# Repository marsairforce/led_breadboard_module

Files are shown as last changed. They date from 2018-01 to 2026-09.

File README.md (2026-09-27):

# A LED indicator module for breadboard development

I became frustrated at having to repeat the boring work of foraging parts, assembling, and then testing status LED circuits for breadboard development with digital logic circuits.

## The Problem

- Most microcontroller projects on a breadboard benefit from several LEDs to show status.
- LEDs operate at voltages lower than logic levels, so require current limiting resistors.
- LEDs typically draw about 10mA or more per LED. Sometimes it is not desirable to load the digital I/O pins from the microcontroller.
  - Quite often a single package device is not capable of sourcing the total current required for a lot of LEDs. For example a 74HC595 is typically capabale of sourcing or sinking up to 70mA. If all of their outputs are active the sum of their currents must not exceed this.
- If we use a simple current limiting resistor, we need to compute the value depending on the forward voltage of the LED and the desired voltage we are working with (today this is either 5V or 3.3V)

So in practice we would would want to set up some kind of buffer with current limiting resistors for the LEDs:

- some transistors and resistors
- or a driver IC like the ULN2803

The whole effort of building LEDs, driver circuits on a breadboard every time is error prone.

And it inconveniently takes up a lot of space on your breadboard.

So I set out to build a module that could be reused between projects.

- [Version 3](./doc/v3.md)
- [Version 2](./doc/v2.md)
- [Version 1](./doc/v1.md)

This project started of as what seemed like a simple activity but turned into a mechanism for a lot of learning.

See Also: [Transistor Theory](./doc/transistor_theory.md)

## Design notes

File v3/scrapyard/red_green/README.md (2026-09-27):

# A red-green LED module for breadboard

This makes use of a bi-color LED. This is a two terminal device. If you supply power one direction it shines red. But if you revese the polarity it shines green.

I wanted to create an easy to use module that lets you change the color and have a mode where there was no output at all (off)

Because each diode has its own different forward voltage the challenge is to use a different resistor or limiting the current. Otherwise the green LED would appear dimmer or the red would appear brighter.  If I just use the constant current sink (or source) this should solve the current problem.

And then a H bridge approach to power the led in alternate directions. Like a DC motor.
But then this requires several small transistors. A first design reduced the package count by using packages with two devices in them.
This had a nice side effect of learning about the SOT-363 package. But I was able to furrher simplify this using a single H bridge IC.
Yes. it is rediculous and over engineered. But it is functional, not very expensive with available parts, and not very much board space. I can see myself adding this indicator to arbitrary projects now.

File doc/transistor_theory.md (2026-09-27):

# Transistor Theory

Before we can talk about transistors it is worth noting

Transistors are inheritly analog devices. They have a 'linear' region and a 'saturation' region.

In the linear region the device is not fully open, where as saturation means we have provided enough inptut to fuly turn on the device.

## Bipolar Transistors

Bipolar Junction Transistors (BJT)s uses two types of charge carriers to conduct electricity: free electrons and electron holes. The junctionrefers to the p-n semiconductor junctions inside the device where different types of silicon meet. A BJT has two of these junctions.

There are two main kinds of BJTs

- NPN: Made of a p-type base sandwiched between two n-type regions (Collector and Emitter). Electrons flow from emitter to collector when a positive current enters the base. They are the most common type because electrons move faster than holes.
- PNP: Made of an n-type base sandwiched between two p-type regions. Current flows in the opposite direction, utilizing electron holes.

BJTs are current-controlled devices. You must pay attention to how much current flows into the base to control the larger current flowing through the collector.

The transistor has a 'gain', $h_{FE}$. This is the static (DC) forward current gain in a common-emitter configuration. Is is the ratio of collector current $I_{C}$ to base current $I_{B}$.

Within the linear region BJTs are used as analog amplifiers. Used extensively in audio amplifiers, radio frequency (RF) circuits, and sensors where signals need a linear boost.

Within the saturation region BJTs are used for discrete Switching, used to turn on indicator lights, buzzers, or relays in simple electronic circuits or for digital logic.

**Common emitter** means:

- For a NPN transistor we measure the current going into the base and into the collector.
- For a PNP transistor we measure the current coming out of the collector and out of the base.

### Some Bipolar Transistor Devices

For the LED modules I investigated packages that contain 1 and 2 transistor devices.

| Transistor 1 | Transistor 2 | Part Number | Package | Vceo | Ic | $h_FE$ | Vce(sat) | Vbe(on) |
|-|-|-|-|-|-|-|-|-|
| NPN | (none) | MMBT3904 | SOT23-3 |  40 V | 200 mA | 100-300 (at 10mA) | 0.2V (at 10mA)<br> 0.3V (at 50mA) | 0.65V-0.85V |
| NPN | NPN | MMDT3904 | SOT-363 |  40 V | 200 mA | 100-300 (at 10mA) | 0.2V (at 10mA)<br> 0.3V (at 50mA) | 0.65V-0.85V |
| PNP | (none) | MMBT3906 | SOT23-3 | -40 V | -200 mA | 100-300 (at -10mA) | -0.3V (at 50mA) | -0.65V - -0.85V |
| PNP | PNP | DMMT3906 | SOT-363 | -40 V | -200 mA | 100-300 (at -10mA) | -0.3V (at 50mA) | -0.65V - -0.85V |
| NPN | PNP | BC846 | SOT-363 |  65V | 100mA | 110-800 (by suffix group) | 0.25 (at 10mA) <br> 0.6V (at 100mA) | 0.58V - 0.77V |

- Vceo (Collector-Emitter Voltage): The absolute maximum voltage the transistor can withstand between the collector and emitter when the base is open. Your circuit voltage should ideally be 20–50% below this rating for safety.
- Ic (Continuous Collector Current): The maximum continuous current the transistor can handle. For standard switching, ensure your load demands significantly less than this limit.
- hFE or β (DC Current Gain): The ratio of collector current to base current (Ic / Ib). Crucial Note: This value drops drastically when the transistor is fully saturated (turned hard ON as a switch). Always look at the datasheet curves, not just the maximum value.
- Vce(sat) (Collector-Emitter Saturation Voltage): The voltage drop across the transistor when it is fully turned ON. Multiplying this by your Ic gives you the conduction power loss (P = Vce(sat) x Ic), which tells you how hot it will get.
-Vbe(on) (Base-Emitter On Voltage): The voltage required across the base and emitter to start turning the transistor on (typically around 0.6V to 0.7V for silicon).
- *MOSFET Transistors*

## Metal Oxide Semiconductor Field Effect Transistor

A MOSFET has three terminals:

- Source (S): Where the charge carriers (electrons or holes) enter the channel.
- Drain (D): Where the charge carriers leave the channel.
- Gate (G): The control terminal that acts like a tap or valve.

MOSFET (Metal Oxide Semiconductor Field Effect Transistor)s are voltage-controlled devices. When you apply a voltage to the Gate, it creates an electric field through the oxide layer. This electric field either opens or closes a conductive channel between the Source and the Drain, allowing a large amount of current to flow with almost no current drawn by the gate itself.

Like BJTs, there are two main kinds of MOSFETS

- N-Channel (NMOS): Turns on when the gate voltage is positive relative to the source. Electrons flow from source to drain. They are generally faster and more efficient.

- P-Channel (PMOS): Turns on when the gate voltage is negative relative to the source. Current flows in the opposite direction using electron holes.

MOSFETs are almost exclusively used in their saturation mode, in this mode they make nearly perfect switches.

MOSFETs require almost zero continuous current at the gate, making them highly efficient for high-speed switching and power applications.\(V_{DSS}\).

They do have

- A gate capacitance. Storing a small bit of charge, the gate works like a capacitor. A higher gate capacitance requires more energy to change the state fo the MOSFET.
- A very small "on" resistance.

### Some popular MOSFET Devices

For the LED modules I investigated packages that contain 1 and 2 transistor devices.

| Transistor 1 | Transistor 2 | Part Number | Package | Vdss | $I_{d}$ | Vgs(th) | Rds(on) | Qg |
|-|-|-|-|-|-|-|-|-|
| NMOS | (none) | BSS123LT1G | SOT23-3 | 100 V | 170 mA | 2.6 V | 6.0 Ω (at Vgs = 10V) | 0.68 nC |
| NMOS | NMOS | 2N7002DW | SOT-363 | 60 V | 115 mA | 2.0 V| 7.5 Ω (at Vgs = 5V) | 0.35 nC |
| PMOS | (none) | BSS84LT1G | SOT23-3 | -50 V | -130 mA | -2.0 V | 10.0 Ω (at Vgs = -5V) | 0.60 nC |
| PMOS | PMOS | BSS84AKS | SOT-363 | -50 V | -160 mA | -2.1 V | 7.5 Ω (at Vgs = -5V) | 0.35 nC |
| NMOS | PMOS | NTJD4105CT1G | SOT363 | N: 20 V <br> P: -8 V |  P: -8 VN: 630 mA <br> P: -775 mA | N: 1.5 V  <br> P: -1.5 V | N: 0.375 Ω (at 4.5V) <br> P: 0.260 Ω (at -4.5V) | N: 0.62 nC <br> P: 0.82 nC |

- Vdss (Drain-Source Voltage): The maximum voltage the MOSFET can block between the drain and source when turned off.
- Id (Continuous Drain Current): The maximum current the device can handle. Note that this is heavily dependent on temperature and proper heat sinking.
- Vgs(th) (Gate-Source Threshold Voltage): The voltage at which the MOSFET just barely begins to conduct. Warning: Do not use this as your driving voltage. A threshold of 2V means it is barely passing microamps.
- Rds(on) (Static Drain-Source On-Resistance): The internal resistance when the MOSFET is fully turned ON. This determines your power loss (P = $I_{d}^2$ * Rds(on)). Lower resistance means less heat. Crucial: Always check what Vgs voltage was used to achieve that Rds(on) rating. If the datasheet specifies Rds(on) at VgsGS = 10V, it will run incredibly hot or fail if you try to drive it with a 3.3V microcontroller.
- Qg (Total Gate Charge): The amount of electrical charge needed to fully turn the gate on and off. Because the gate acts like a capacitor, a high Qg requires a strong gate-driver circuit to switch quickly without overheating.

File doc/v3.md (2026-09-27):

# LED Breadboard Module Version 3

Taking what I have learned from the v2.1 design:

- There is no point in having a pulldown resistor on the base of the transistor. These are bipolar and do not need this pulldown like a MOSFET would.
- The LED and transistors get kind of hot when pushing more than 5v into them. This is beacuse the current is proportional to voltage and I just had a simple current limiting resitor for the LED.
- The current through the LED was kind of high, about 20 mA each. We can use much less, under about 10 mA and get the same useful brightness.
- The base resistor is too small. For the amount of gain in the transitor, we are sinking more current into the transistor.
  This causes a lower impedance and could load digital logic or IO ports more than what I had designed these self-buffering LED indicators to do for us.

## Design Constraints

I have learned to state what it is I want to achieve up front so this is my road map.

My priority at this time

- Support a range of input voltages (so a constant current source for the LED)
- High impedance control inputs (to not load the signal we are monitoring)
- Option for an active low input to control the LED.
- Use an 0806 package for LED, larger, easier to see?
  - no. more investigation shows larger packages do not make a brighter LED.
- A mode to allow a bi-color LED to be operated with a control signal and an output enable.
  - This turned out to be pointless.
  At the time I had this point I was thinking there would be a device with true anti-parallel wiring, two LEDs with two wires on the package.
  In practice the LEDs I have found with more than one color just have multiple input pins.
- Support for standard logic IC families - to create a breadboard module for a 74HC595 (a serial in, parallel out shift register), that functions as the 74HC595 should, but with lights for the outputs. And in general other popular ICs, like discrete logic gates.
  I was imagining a TSSOP package IC with the drivers so the footprint is a slightly larger DIP kind of package with the same pin out of the device.
- Investigate a modyke where A single LED can be dropped into breadboard.
  A three terminal device that has two pins to go into the breadboard power rails and a pin that can go into the row that presumably has an IC pin.
  So we can just drop an indicator for a single pin of an existing IC
- A 'universal LED'. A Two terminal device that looks like a 3mm or 5mm thru hole LED. It accepts power, any polarity and a range of voltage. It just lights up. Simple indicator, like a regular old light bulb, but its a LED.

## Learning and Theory

I did a side quest to investigate and learn about different topologies:

- high side drive
- low side drive
- constant current source
- constant current sink

The notes are in the [building blocks](building_blocks.md) document.

While iterating with these designs I discovered there are devices that have two transistors in a single package. The use case being for multiple LED on a module we could benefit from using a dual device in a single package. My notes and discovery are in the [transistor theory](transistor_theory.md) document.

Another discovery during this round of design was realizing how much smaller a SOT-363 package is from a SOT23-3. It was enough that it made more sense to just make every device be in the SOT-363 package and not even use SOT23-3 packages.

The next discovery was there exists a product that provides constant current regulation in a single package. I no longer need to build out my own discrete components. Four parts become one part.

And then the realization, I still need pull down resistors for the MOSFET transistors, But instead of individual resistors I can use a resistor network. Single package in a 1206 footprint with 8 100K resistors.

## Variants

Since some of the constraints and use cases are contradictory, I decided I would just define a model (uncreatively using letters) to articulate each variant.

Weather or not we actually get around to designing and building these has yet to be seen.

| Model | # LEDs | Color | Drive | Active High | Active Low |  OE | Desc |
| ----- | --- | ----- | ----- | :---: | :---: | :---: | ---: |
| A | 8 | Red | High  | * | | | 8 red LED, high side drive, active high control |

So model "A" is the only one I have had before with v2 design.

Future considerations

| Model | LED | Drive | Active High | Active Low | OE | Desc |
|----|-----|---|:---:|:---:|:-:|-----:|
|  C | Red | High  | * | * | | Single red LED, high side drive, both active high and active low control |
|  D | Red | Low | *  |  | | Single red LED, low side drive, active high control |
|  E | Red | Low |  | * | | Single red led, low side drive, active low control |
|  F | Red | Low | *  | * | | Single red led, low side drive, both active high and active low control |

### Model A

We just had the (1) BSS123 in our circuit. So it was straight forward to replace it with the 2N7002DW to get a SOT-363 package.

This then made sense to share the second device with another LED channel. Since we are building 8 channels in one module here this helps to reduce the parts count.

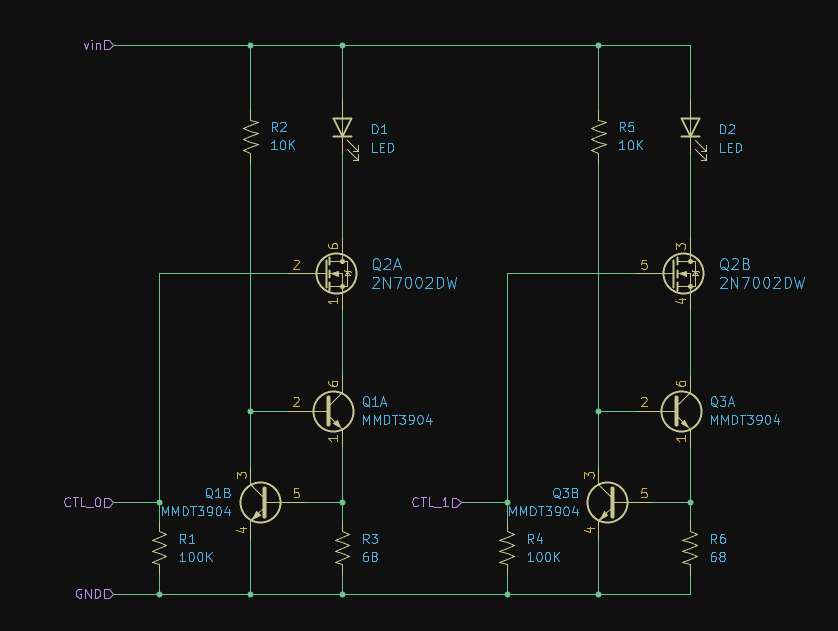
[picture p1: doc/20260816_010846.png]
V3.1 Model A design


This was designed with the transistor constant current sink we started with before we discovered the single package constant current regulator device

I had laid it out as module about the same size as the v2.1 build. .

Front:

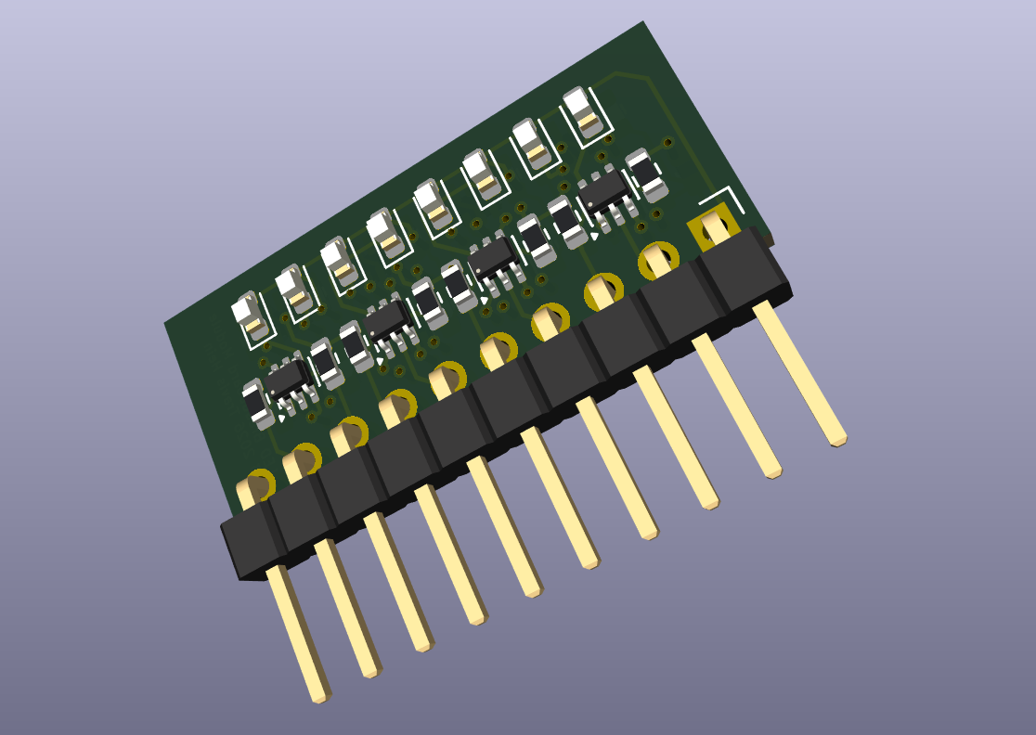
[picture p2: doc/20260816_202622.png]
3d model front


Back:

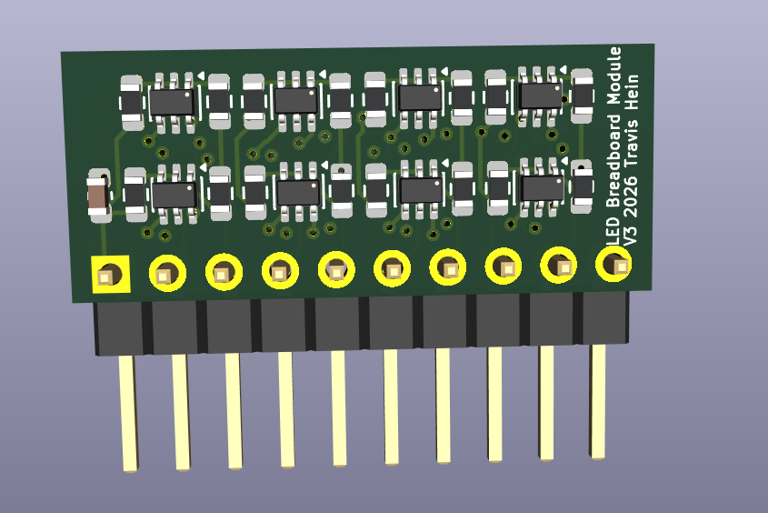
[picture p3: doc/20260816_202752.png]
3d model back


But since I did not build this, instead went ahead with the single package current regulator approach.

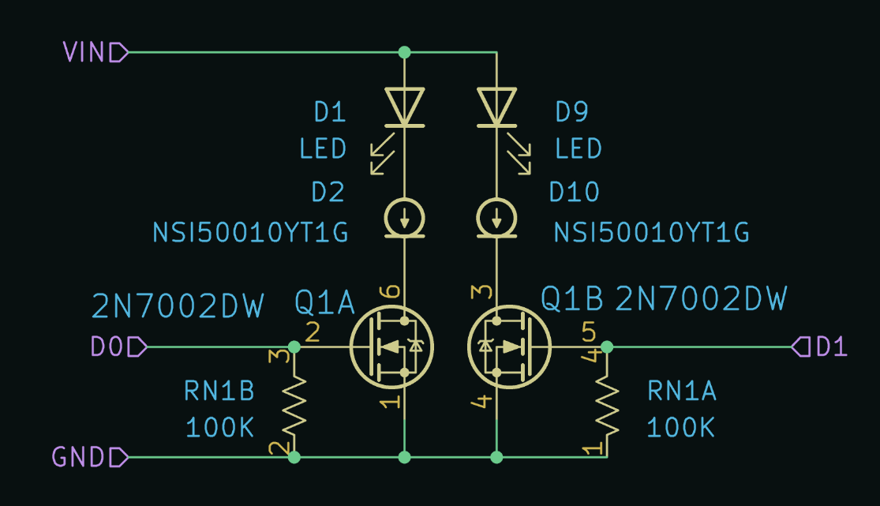
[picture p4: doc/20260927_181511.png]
v3.1 element


The current regulators in to replace the pair of BJTs. Four devices down to one.

Again using the two devices in a single package for the MOSFETs.

New this iteration: using resistor networks. I first tried a single package with 8 resistors, but it was a mess to route. Here we have two resistors in one package. Which gives us half as many packages for the pull down resistors.

And then scale out to get 8 LEDs.

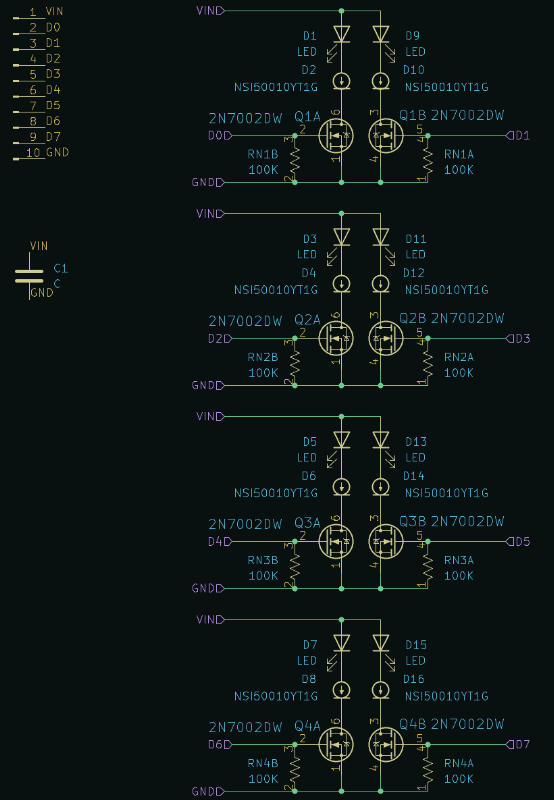
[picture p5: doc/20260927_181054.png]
v3.1 schematic


Front:

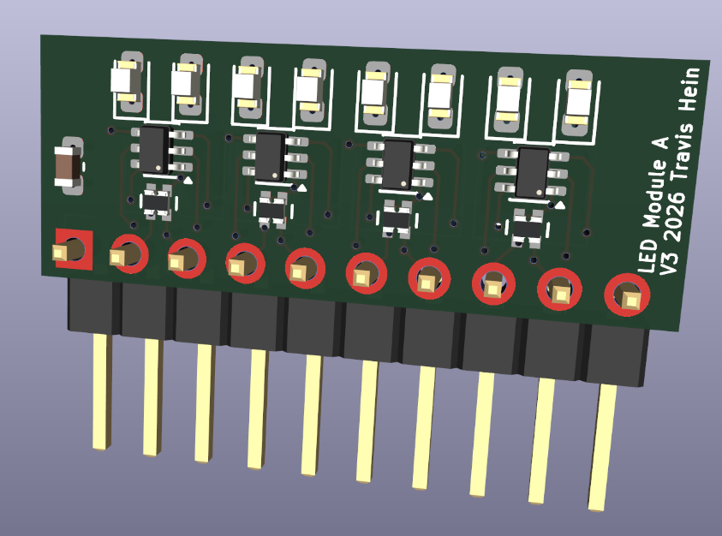
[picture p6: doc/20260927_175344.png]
v3 front


Back:

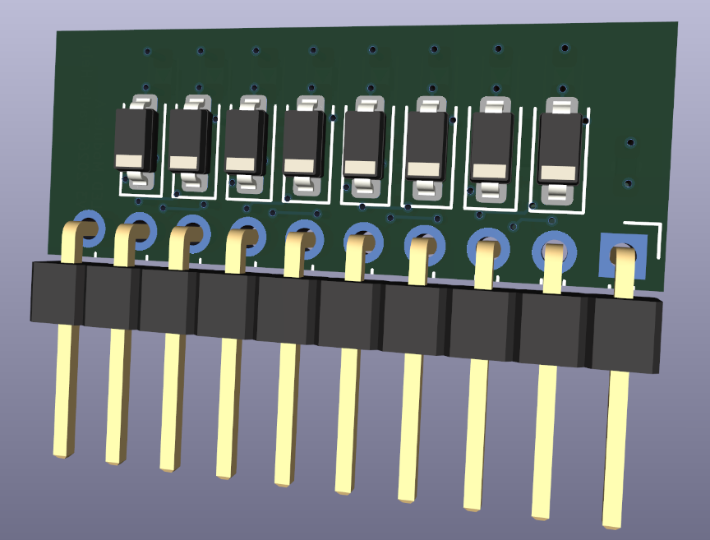
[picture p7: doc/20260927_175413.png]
v3 back


Way less parts!

> I noticed this time the LED are vertical instead of horizontal like they were on V2.
> I think i prefer this as it providers closer grouping visually, to indicate the 8 bits easier.

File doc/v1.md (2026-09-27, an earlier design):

# LED Breadboard Module Version 1.0

This was made in 1999. At the time, I was a student of the University of Manitoba completing my undergrad degree in computer engineering.

We had electronics labs with wires and breadboards and discrete 74xx digital logic ICs. Our assignments were to wire up logic gates and simple sequential logic circuits. The inputs were toggle switches and the outputs were LEDs.

The lab was only a few hours long. Everytime we had to start from a blank breadboard, go collect parts, cut and strip wires, build the circuit, do the lab work, and then tear it all down and put everything away.

I noticed I would spend a lot of time, and a lot of breadboard realestate wiring up the output LEDs. As we progressed to creating 4 bit half adders and later working with 8 bits for a data bus, there was a lot of LEDs.

I liked to have LEDs on address bus too, not required for the lab work but it made things look pretty.,

I wanted something that was easy to plug into the lab breadboards,
use for the duration of the lab, and then take it home with me. Something that had the nuisance of resistors and a driver circuit that would not load the logic level outputs from the devices.

What I came up with was a small DIP socket sized module

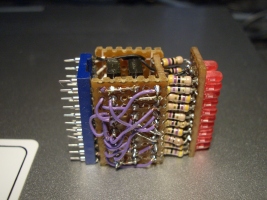
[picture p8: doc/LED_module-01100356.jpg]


This was a cordwood style construction, using perfboard and a 20 pin DIP socket.

The buffer here was 2x 74LS373 ICs.

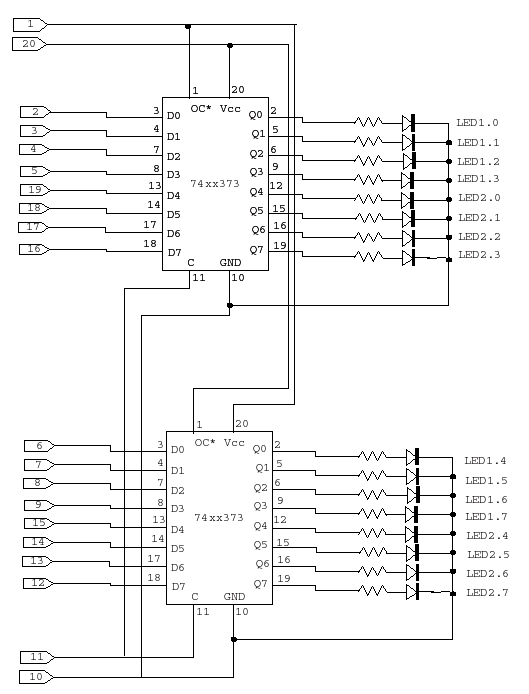
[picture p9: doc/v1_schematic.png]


Each It supported two rows of 8 LEDs on the top. Where the LED
and resistors were thru-hole style. The extra LED were for showing the output enable and latch mode feature per row. Though these were not buffered. I think I wanted to be able to have the LEDs hold their state for some lab work...

The 3 mm round LED had to be filed to rectangle shape to
allow them to fit closer together. At the time I did not have rectangular LEDs.
And the resistors were assembled creatively
as one of the leads so was also the mechanical support for the LEDs

Parts list:

- Two 74xx373 series chips
- A 20 pin DIP socket, preferably a sturdy one, I used one with the machined legs. Wire wrap socket would be good too.
- (16) small LED's. The standard sized ones are too big.
- (16) 4.7k resistors
- 2x small pieces of solder pad hole circuit board for the sides. My pieces are 6 holes x 10 holes.
- 2x small pieces of solder pad hole circuit board for the led assembly. My pieces are 4 holes x 10 holes
- some wirewrap or similar fine wire. I used some 22 gauge solid conductor category 5 network cable type wire.

It was novel at the time because it enabled me to have 16 individual status LEDs in the footprint of a 20 pin DIP socket on a breadboard.

Showing up to do my labs was awesome. Plug in the module. Wire up the logic circuits, but not needing to spend a lot of time assembling the LED indicators and drivers and current limiting resistors.

The only downside here was if there was a desire to have status LEDs spread out over the entire breadbaord, like a chip enable beside the chip that is being enabled.

We now had all of the LEDs in one location and creating a diagram to map out the inventory of which one meant what function was essential.

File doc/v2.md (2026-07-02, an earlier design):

# LED Breadboard Module Version 2

Created spring 2017

Using surface mount components, place 8 LED, resistors, and transistor drivers.

Design a circuit board in Kicad, have it made at OSHPark.

* A single 10 pin footprint.

Board dimensions 29mm (w) x 16mm (h)

It was not as many LEDs as the v1 model. But we could just use two modules for the same effect. The footprint of this module was a single row, not a DIP format as well.

The 0603 package surface mount LEDs are very bright and easy to see.

The board works well with 3.5V as well as 5v.

I found using a 74373 package this time to be limiting because

* it required 5V. I wanted something that was flexible to be used woth both 5V and 3.3V logic.
* The physical footprint of the soic device is not very convenient to place into this small planar footprint.

I opted to use some small surface mount transistors and resistors.

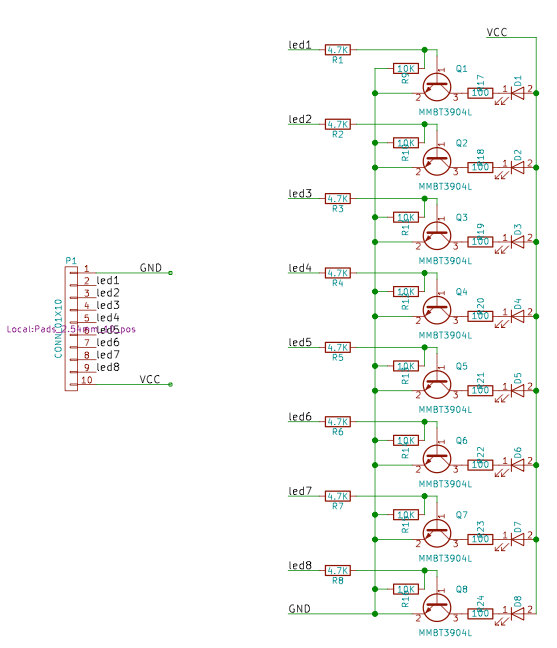
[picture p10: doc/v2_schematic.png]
v2 schematic


> In hindsight the pulldown resistors are unnecessary here.

## Version 2.1

Created late spring 2017

I was not happy with how tall the V2.0 module was.
At the time I built it I was still learning how to lay out PC boards with Kicad.

Here all I did was arrange the same components as before but used a 4 layer board.

This allowed me to pack the components densely onto both sides of the board.

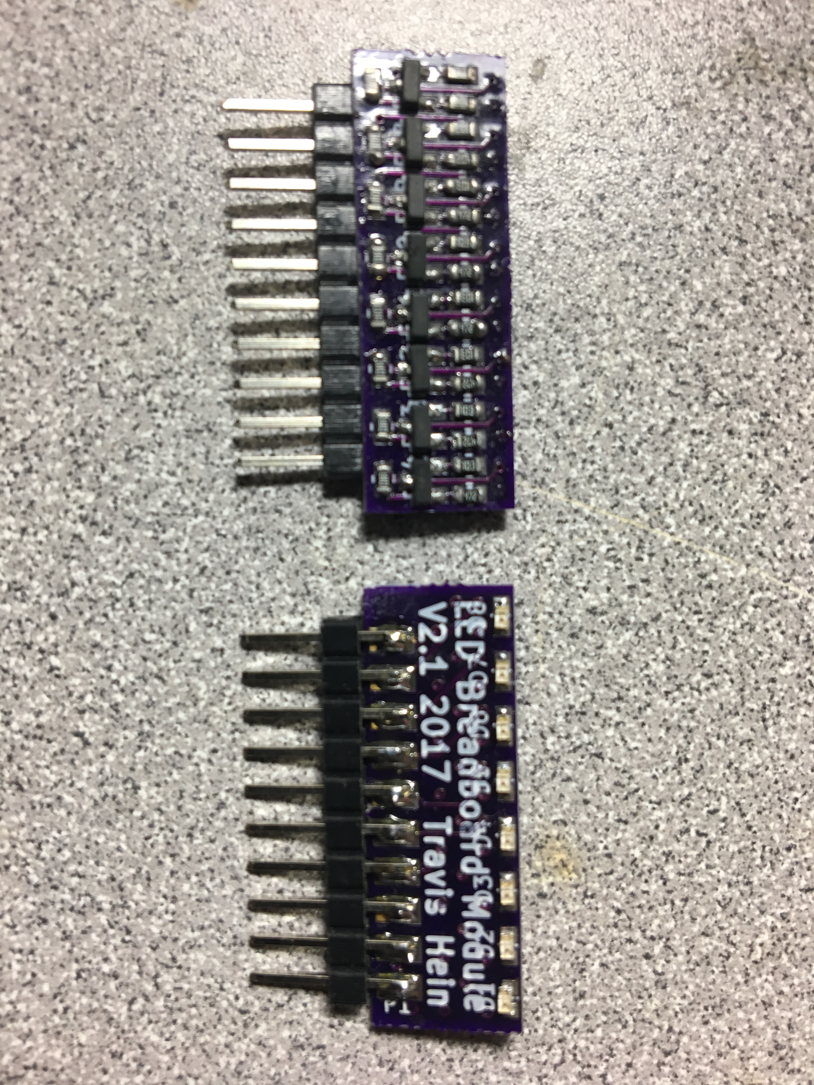
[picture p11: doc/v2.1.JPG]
v2.1 hardware


This cut the board size down to 19mm (w) x 10mm (h)

I know it doesn't sound like much, but it just looks a lot better.

And it fits well onto breadboards. As a lower profile it is not in the way anymore
as both the v1 and v2 iterations were sort of tall and would stick up enough
to get knocked off the breadboard if you accidentally bumped it or wires got tugged across it.

I no longer have latching or output enable features here as well. But for my current use cases this was not a significant problem.

Most of the time I was using a 74'595 serial in to parallel out shift register to drive these, and that would provide the latching feature for me.

Over time using it I found other use cases beyond the original use, for 5v and 3.3v microcontroller circuits.
But I discovered when driving more than 5v into this the LEDs and transistors get warm. This is beacuse they draw current proportional to voltage. This set me on the path to design the V3 module.

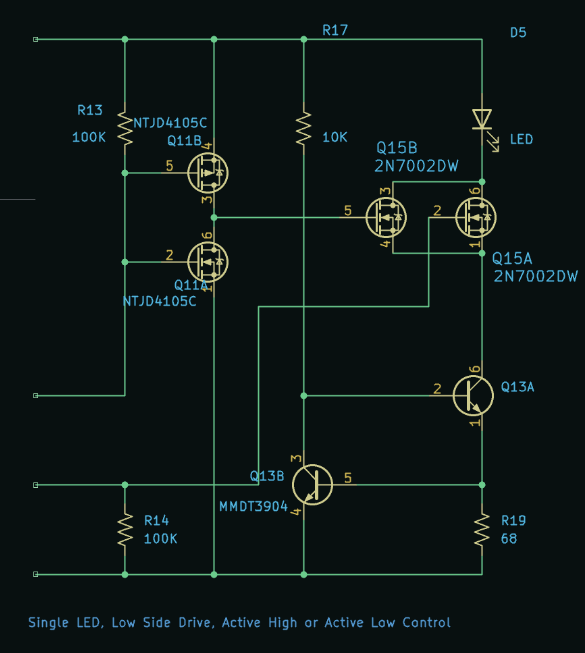
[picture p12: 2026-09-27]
doc/single_low-side_active-high-or-low.png

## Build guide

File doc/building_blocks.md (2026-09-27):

# Building Blocks

This was a side quest during v3 design to invesitagate different topologies

## Constant Current Source or Sink

In electronics, a constant current source or constant current sink is a specialized circuit that forces a precise, fixed amount of current through a load, regardless of changes in the load's resistance or variations in the supply voltage.

### A constant current source using BJTs

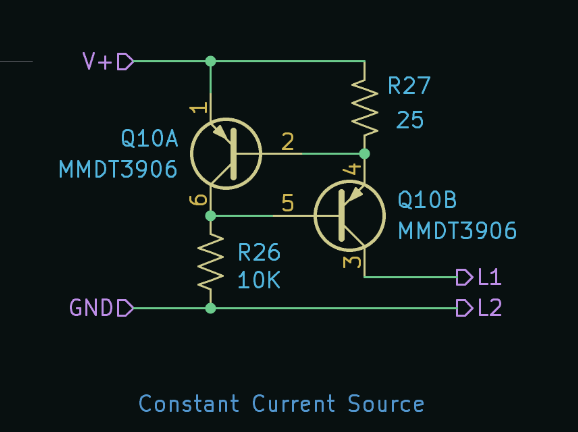
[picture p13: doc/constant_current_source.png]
constant current source


- Q10B: The primary pass transistor (PNP). It conducts the regulated current out of its collector (Pin 3) to the L1 output.
- R27 (\(25\ \Omega\)): The current-sensing resistor. It sits between \(V+\) and the emitter of Q10B, converting the output current into a small voltage drop.
- Q10A: The feedback control transistor (PNP). It monitors the voltage drop across R27 and throttles Q10B.
- R26 (\(10\text{ k}\Omega\)): The pull-down resistor that initially pulls the base of Q10B toward Ground to turn the circuit on.

When power (\(V+\)) is applied, current flows from \(V+\) through R27, past the emitter-base junction of Q10B, and down through R26 to Ground. This pulls Q10B's base low, turning it ON and sourcing current out of L1.

As the load current flowing out of L1 increases, the current passing through R27 increases, causing a voltage drop across it.

Because the emitter of Q10A is tied to \(V+\) and its base is tied to the other side of R27, the voltage drop across R27 is exactly the emitter-base voltage ($V_{EB}$) of Q10A. Once this voltage drop hits roughly \(0.65\text{ V}\), Q10A turns ON.

When Q10A turns on, it passes current from \(V+\) directly into the base of Q10B (Pin 5). This pushes Q10B's base voltage up toward \(V+\), starving its emitter-base drive and forcing Q10B to squeeze shut slightly.

This instantly limits the output current, keeping it perfectly flat even if the resistance of the load fluctuates.

## A constant current sink using BJTs

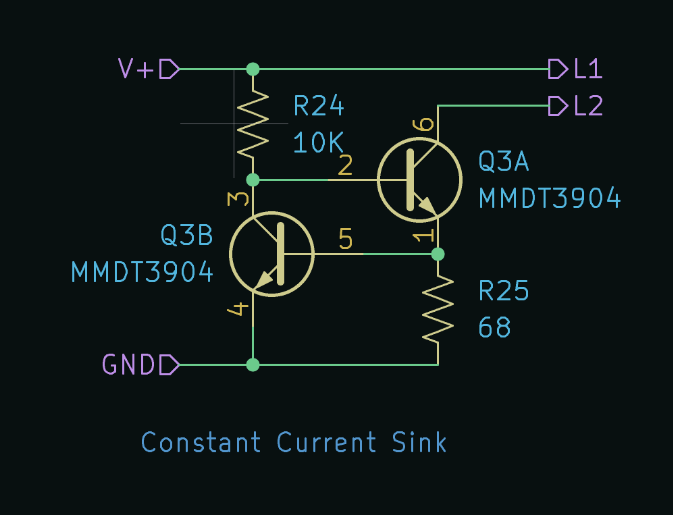
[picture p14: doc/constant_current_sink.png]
constant current sink


- Q3A: The primary pass transistor. It does the heavy lifting by pulling current from the load attached to L2.
- R25 (\(68\ \Omega\)): The current-sensing resistor. It converts the sinking current into a small voltage drop.
- Q3B: The feedback control transistor. It monitors the voltage across R25 and throttles Q3A to keep the current steady.
- R24 (\(10\text{ k}\Omega\)): The pull-up resistor that provides the initial turn-on current to the base of Q3A.

When power (\(V+\)) is applied, current flows through R24 into the base of Q3A (Pin 2). This turns Q3A ON, allowing current to flow from the load (L2) through Q3A and down through R25 to Ground.

As the load current increases, the voltage drop across R25 rises according to Ohm's Law (\(V = I \times R\)).

The top of R25 is connected directly to the base of Q3B (Pin 5). Once the current is high enough that the voltage drop across R25 hits roughly \(0.65\text{ V}\) (the threshold needed to turn on a silicon transistor), Q3B begins to turn ON.

As Q3B turns on, it begins to skim current away from the base of Q3A (Pin 2) and dumps it straight to Ground (Pin 4). This starves Q3A's base, forcing Q3A to turn off slightly and restrict the load current.

This negative feedback loop happens instantaneously, locking the current at a fixed, stable value regardless of variations in \(V+\) or the load's resistance.

## A constant current sink using a specialized device

It was a lot of fun and very educational to investigate using BJTs as constant current control.

But then I discovered that 'constant current regulation' is a thing.

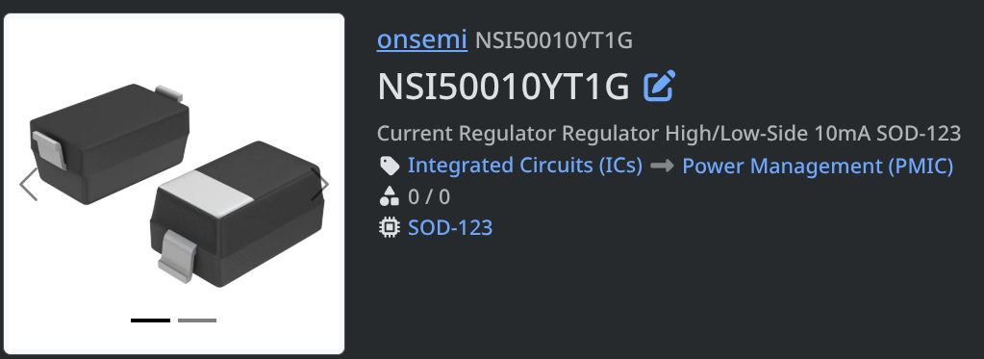
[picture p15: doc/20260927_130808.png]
constant current device


This NSI50010YT1G is available on [DigiKey](https://www.digikey.ca/en/products/detail/onsemi/NSI50010YT1G/2271548) for $0.52 each, comes in a single SOD-123 package.

So clearly for less parts in the BOM for very slightly more cost. Since my priority is less stuff and smaller footprints, this is the winner.

We can see, for the low side drive, active high configuration, this simplifies the number of parts from 6 down to 4

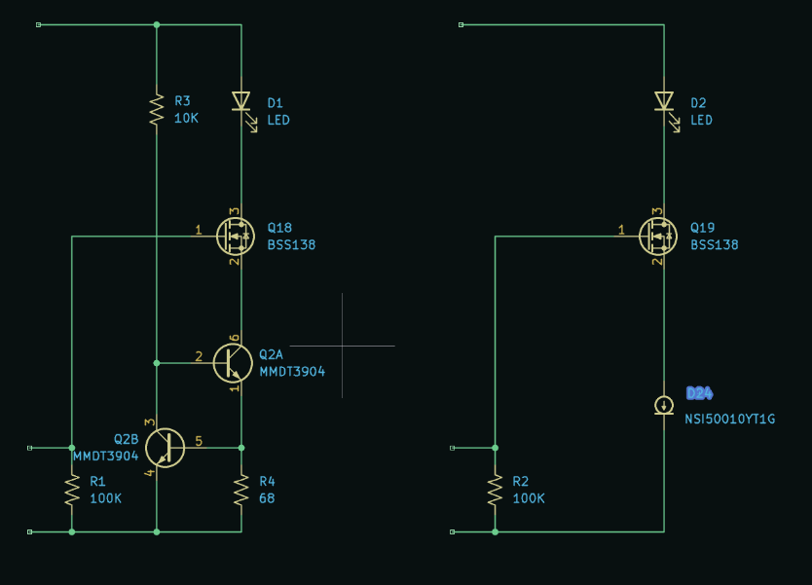
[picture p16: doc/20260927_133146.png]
current device


Though it is not as 'fun' looking circuit.

## High Side Drive

This is when we have the switching part above the load.

In this case having a switch above the LED

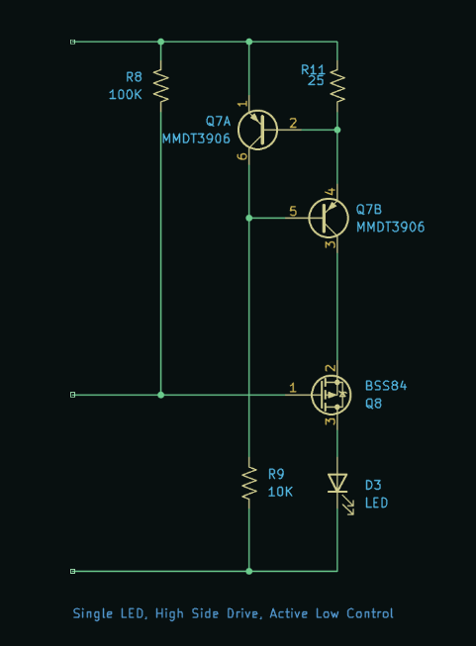
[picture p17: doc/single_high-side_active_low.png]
high side drive


A Use case for this type of circuit might be

- To drive common cathode 7-Segment displays
- When we want an active low input, without needing an inverter (if we were using a low-side drive)

## Low Side Drive

This is when we have the switching part below the load.

In this case having a switch below the LED

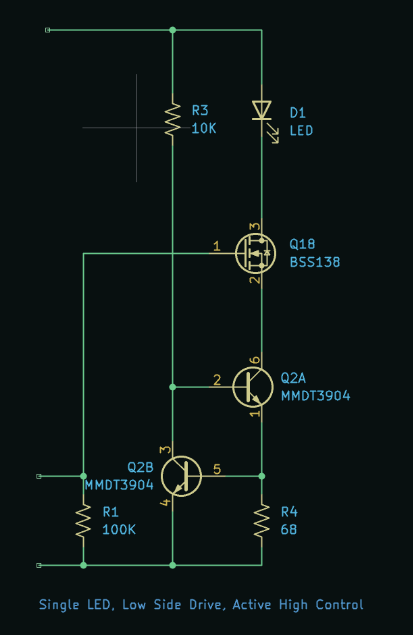
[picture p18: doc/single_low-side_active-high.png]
low side drive


This has use cases for:

- a common anode 7-segment LED display
- the configuration of previous LED breadboard modules.

## Active High Control

This is when we want to use a logic level 1 to mean turn on the thing.

In this case using a logic level 1 to turn on a LED.

We have already shown this above for the low side drive.

If we want to have active high behavior for a high side drive we just add an inverter

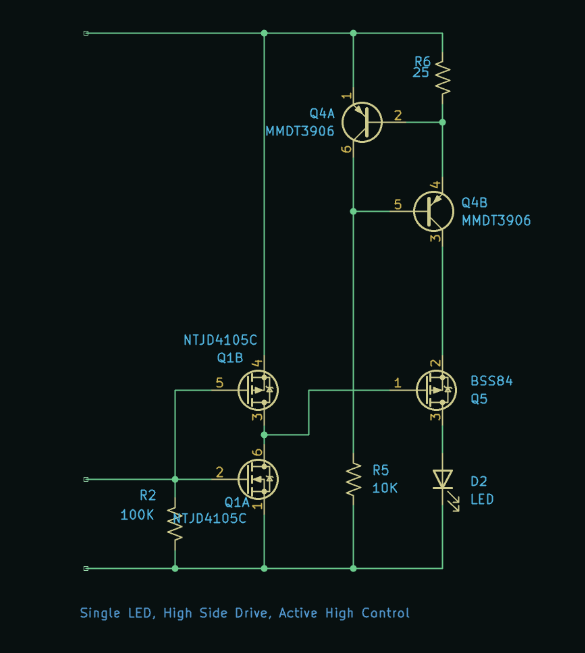
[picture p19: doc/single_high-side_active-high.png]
active high high side drive


## Active Low Control

This is when we want to use a logic level 0 to mean turn on the thing.

In this case using a logic level 0 to turn on a LED.

> This use case comes up a lot in our digital logic adventures. Most "output enable" or "chip select" pins are active low.
>
> Before I would need to place an inverter on the breadboard to flip the logic level to make the LED turn on for active low signals.

We have alrady seen the active low for high side drive above.

To realize an active low for low side drive we just add an inverter.

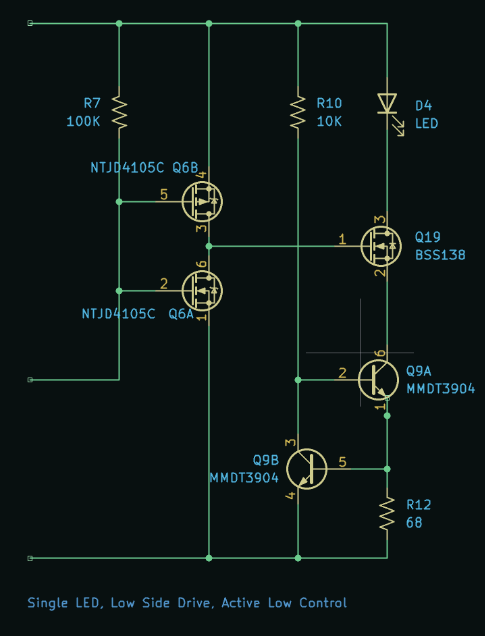
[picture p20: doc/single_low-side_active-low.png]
low side drive active low


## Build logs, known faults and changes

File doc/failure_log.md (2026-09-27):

# Failed Attempts

> This is more of a log of the evolution and discovery during this build.

## V3 failed design

The original v3 module was designed in Spring 2021

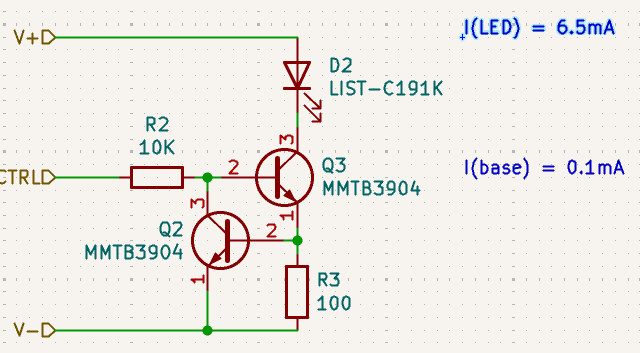
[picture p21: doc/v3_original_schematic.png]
v3 schematic


The bottom transistor (Q2) with resistor (R3) works as a constant current source. As current across R3 increases, the voltage drop will also increase, turning on Q2 which will work to lower the base current going into Q3.

With R2 as a high value this will not load the input. The drive current is now around 0.1mA. Though it could be less, I just don't have the ability to measure current this small.

The gain of Q3 seems to provide around enough current to drive the LED over a wider range of input voltages.

2021: Ordered some boards on OSH Park. Waiting for those to come in now.

2026: Fast forward, somehow it is summer 2026. I have had the boards for years, moved. Everything was in storage. Dig out the parts. Trim mouse bites off boards. I can't remember now what distracted me from finishing these.

This time I investigated creating solder paste stencils using 3D printer and FreeCAD. But while waiting for solder paste to arrive from Amazon, lets try to assemble one LED circuit.

I discovered I made a mistake in KICAD, choosing the footprint for the 2N3904, which in the TO-92 case has pin 1 as emitter, pin 2 as base. Where here with the MMBT3904 in the SOT-23 package, pin 1 is the base.

My original schematic was incorrect: The base should be pin 1!

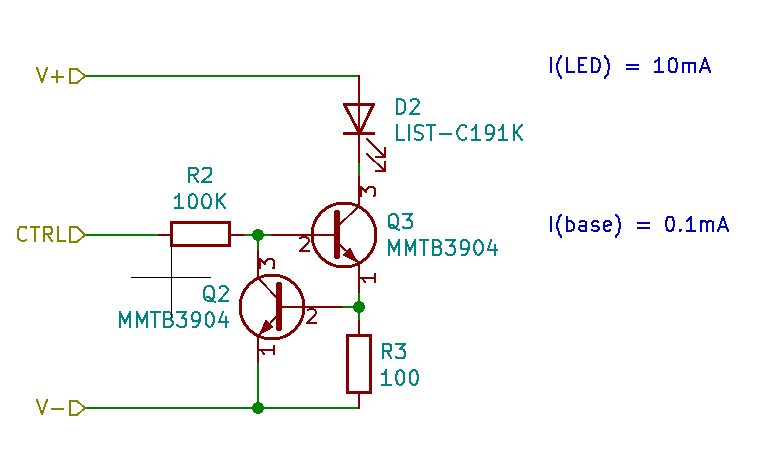
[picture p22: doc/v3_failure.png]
failed v3 design


I also incorrectly had 100K resistor to drive the base, which is way too low current for practical use with 3.3v. I must have just tested it with 12v.

Okay, so we will need new boards. I am upsed that 2021 Travis did not notice this error. And I don't understand how I would have missed this, I had it correct in the V2 boards.

### A Red/Green LED Module with Output Enable

This is model G, or H (if we just reverse the LED) - Bi-color LED, control: 1=green, 0=red, with output enable

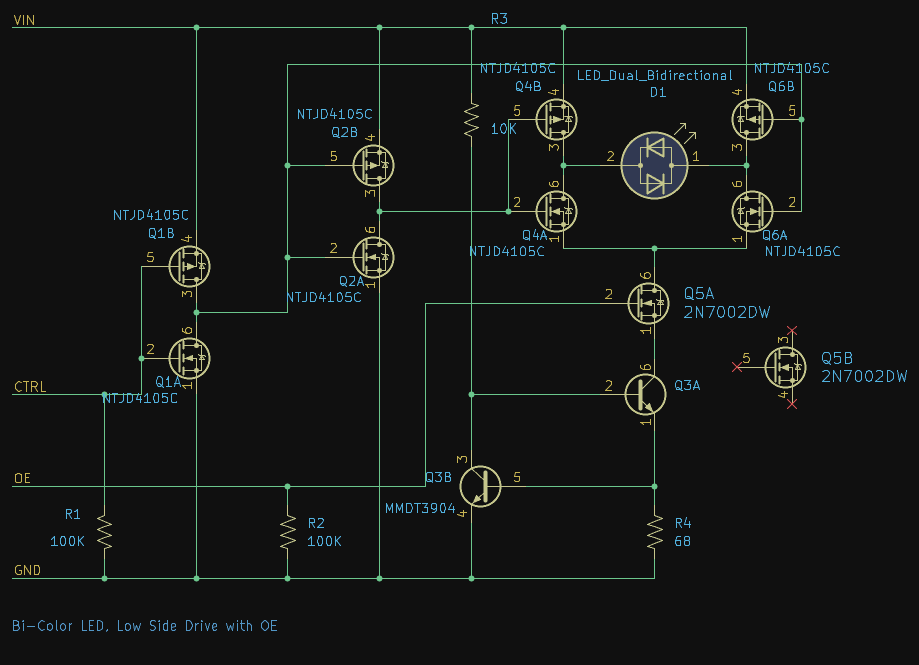
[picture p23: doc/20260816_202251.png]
Red Green LED module


This borrows the same constant current sink and MOSFET input technology from the V3.1 red LED module.

We also take advantage of the using a double device package to get something in the SOT-363 packaging. Here we just not use the second device. This makes laying things out a lot easier.

This actually helps us a lot given we are trying to build all this stuff into a tiny PCB

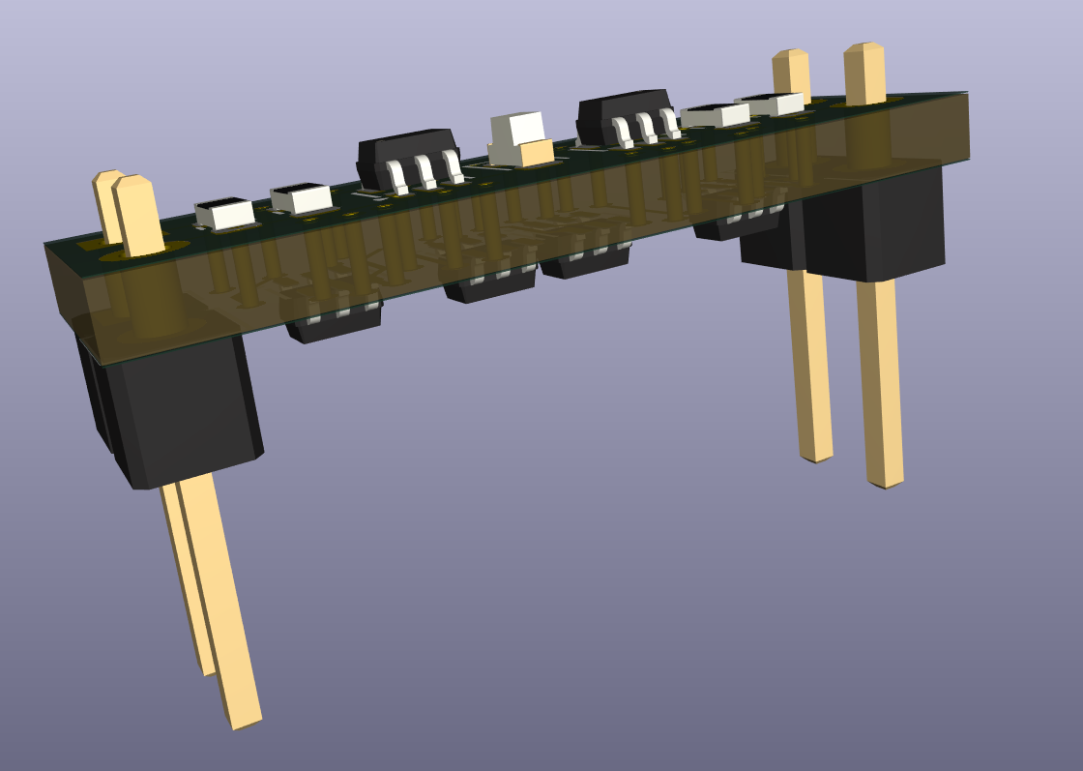
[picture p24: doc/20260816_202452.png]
red green 3d model


The entire board is only 2 header pins wide and spance a bit more than a DIP package.

And then the realization that this LED is not a two package anti-parrel LED, but instead two separate LED, with 4 connectors. And they are wired in parallel diode orientation to boot. So even if I just soldered both pads on a side together I would just have two LEDs on at the same time with one direction and then none LEDs on with the other direction.

I kind of of did not see the point of building this module if it is just two LEDs.

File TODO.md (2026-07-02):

# Things to consider for future revisions

* Support a latch output
* Output enable
* Support inverted input (active low)
* An option to have serial data in (like a '595 operation).

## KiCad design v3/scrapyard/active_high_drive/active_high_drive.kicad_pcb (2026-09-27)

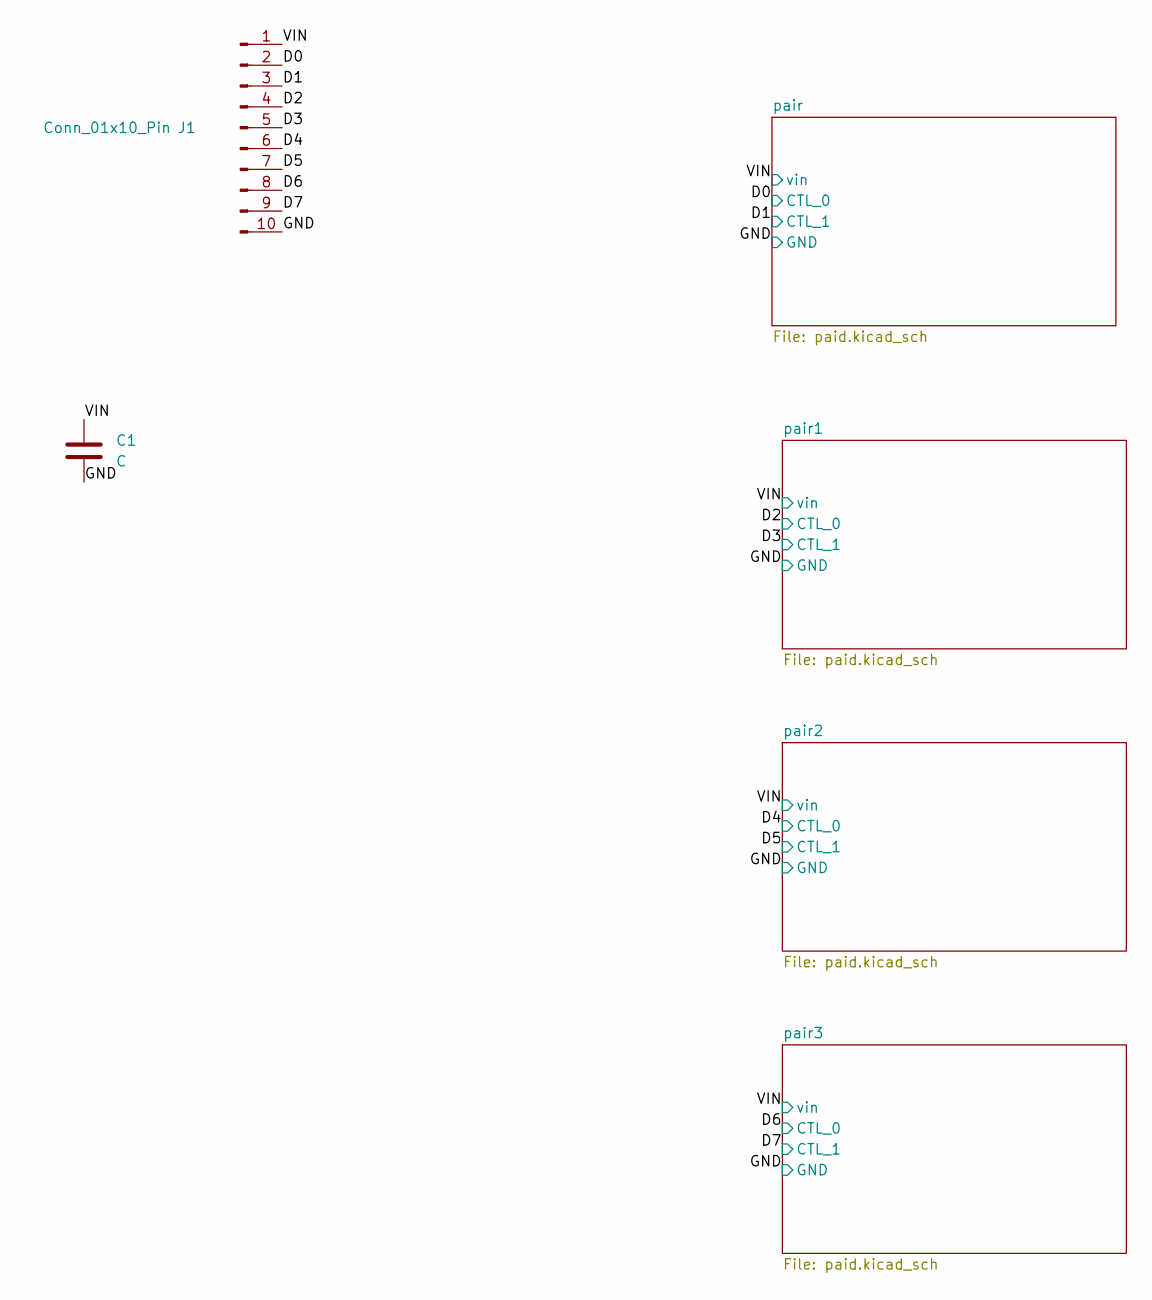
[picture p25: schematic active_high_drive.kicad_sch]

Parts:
C1: C; C_0603_1608Metric
J1: Conn_01x10_Pin; PinHeader_1x10_P2.54mm_Horizontal

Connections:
/D0: J1.2; also elsewhere on the board
/D1: J1.3; also elsewhere on the board
/D2: J1.4; also elsewhere on the board
/D3: J1.5; also elsewhere on the board
/D4: J1.6; also elsewhere on the board
/D5: J1.7; also elsewhere on the board
/D6: J1.8; also elsewhere on the board
/D7: J1.9; also elsewhere on the board
/GND: C1.2, J1.10; also elsewhere on the board
/VIN: C1.1, J1.1; also elsewhere on the board

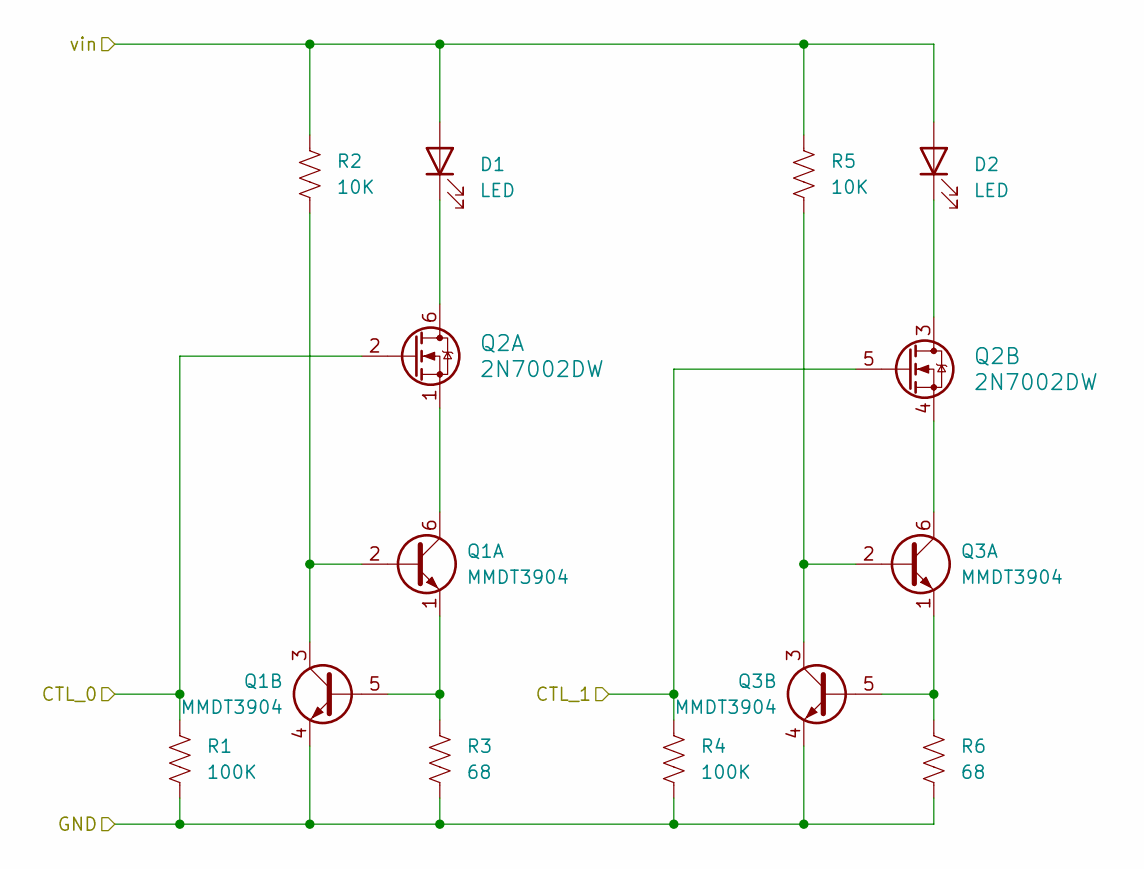
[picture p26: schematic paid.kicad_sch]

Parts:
D1, D2: LED; LED_0603_1608Metric
Q1, Q3: MMDT3904; SOT-363_SC-70-6
Q2: 2N7002DW; SOT-363_SC-70-6
R1, R4: 100K; R_0402_1005Metric
R2, R5: 10K; R_0402_1005Metric
R3, R6: 68; R_0402_1005Metric

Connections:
/D0: Q2.2 (G), R1.1; also elsewhere on the board
/D1: Q2.5 (G), R4.1; also elsewhere on the board
/GND: Q1.4 (E2), Q3.4 (E2), R1.2, R3.2, R4.2, R6.2; also elsewhere on the board
/VIN: D1.2 (A), D2.2 (A), R2.1, R5.1; also elsewhere on the board
unnamed: D1.1 (K), Q2.6 (D)
unnamed: D2.1 (K), Q2.3 (D)
unnamed: Q1.2 (B1), Q1.3 (C2), R2.2
unnamed: Q1.6 (C1), Q2.1 (S)
unnamed: Q1.1 (E1), Q1.5 (B2), R3.1
unnamed: Q2.4 (S), Q3.6 (C1)
unnamed: Q3.2 (B1), Q3.3 (C2), R5.2
unnamed: Q3.1 (E1), Q3.5 (B2), R6.1

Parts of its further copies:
D3, D4, D5, D6, D7, D8: LED; LED_0603_1608Metric
Q4, Q6, Q7, Q9, Q10, Q12: MMDT3904; SOT-363_SC-70-6
Q5, Q8, Q11: 2N7002DW; SOT-363_SC-70-6
R7, R10, R13, R16, R19, R22: 100K; R_0402_1005Metric
R8, R11, R14, R17, R20, R23: 10K; R_0402_1005Metric
R9, R12, R15, R18, R21, R24: 68; R_0402_1005Metric

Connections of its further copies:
/D2: Q5.2 (G), R7.1; also elsewhere on the board
/D3: Q5.5 (G), R10.1; also elsewhere on the board
/D4: Q8.2 (G), R13.1; also elsewhere on the board
/D5: Q8.5 (G), R16.1; also elsewhere on the board
/D6: Q11.2 (G), R19.1; also elsewhere on the board
/D7: Q11.5 (G), R22.1; also elsewhere on the board
/GND: Q4.4 (E2), Q6.4 (E2), Q7.4 (E2), Q9.4 (E2), Q10.4 (E2), Q12.4 (E2), R7.2, R9.2, R10.2, R12.2, R13.2, R15.2, R16.2, R18.2, R19.2, R21.2, R22.2, R24.2; also elsewhere on the board
/VIN: D3.2 (A), D4.2 (A), D5.2 (A), D6.2 (A), D7.2 (A), D8.2 (A), R8.1, R11.1, R14.1, R17.1, R20.1, R23.1; also elsewhere on the board
unnamed: D3.1 (K), Q5.6 (D)
unnamed: D4.1 (K), Q5.3 (D)
unnamed: D5.1 (K), Q8.6 (D)
unnamed: D6.1 (K), Q8.3 (D)
unnamed: D7.1 (K), Q11.6 (D)
unnamed: D8.1 (K), Q11.3 (D)
unnamed: Q4.2 (B1), Q4.3 (C2), R8.2
unnamed: Q4.6 (C1), Q5.1 (S)
unnamed: Q4.1 (E1), Q4.5 (B2), R9.1
unnamed: Q5.4 (S), Q6.6 (C1)
unnamed: Q6.2 (B1), Q6.3 (C2), R11.2
unnamed: Q6.1 (E1), Q6.5 (B2), R12.1
unnamed: Q7.2 (B1), Q7.3 (C2), R14.2
unnamed: Q7.6 (C1), Q8.1 (S)
unnamed: Q7.1 (E1), Q7.5 (B2), R15.1
unnamed: Q8.4 (S), Q9.6 (C1)
unnamed: Q9.2 (B1), Q9.3 (C2), R17.2
unnamed: Q9.1 (E1), Q9.5 (B2), R18.1
unnamed: Q10.2 (B1), Q10.3 (C2), R20.2
unnamed: Q10.6 (C1), Q11.1 (S)
unnamed: Q10.1 (E1), Q10.5 (B2), R21.1
unnamed: Q11.4 (S), Q12.6 (C1)
unnamed: Q12.2 (B1), Q12.3 (C2), R23.2
unnamed: Q12.1 (E1), Q12.5 (B2), R24.1

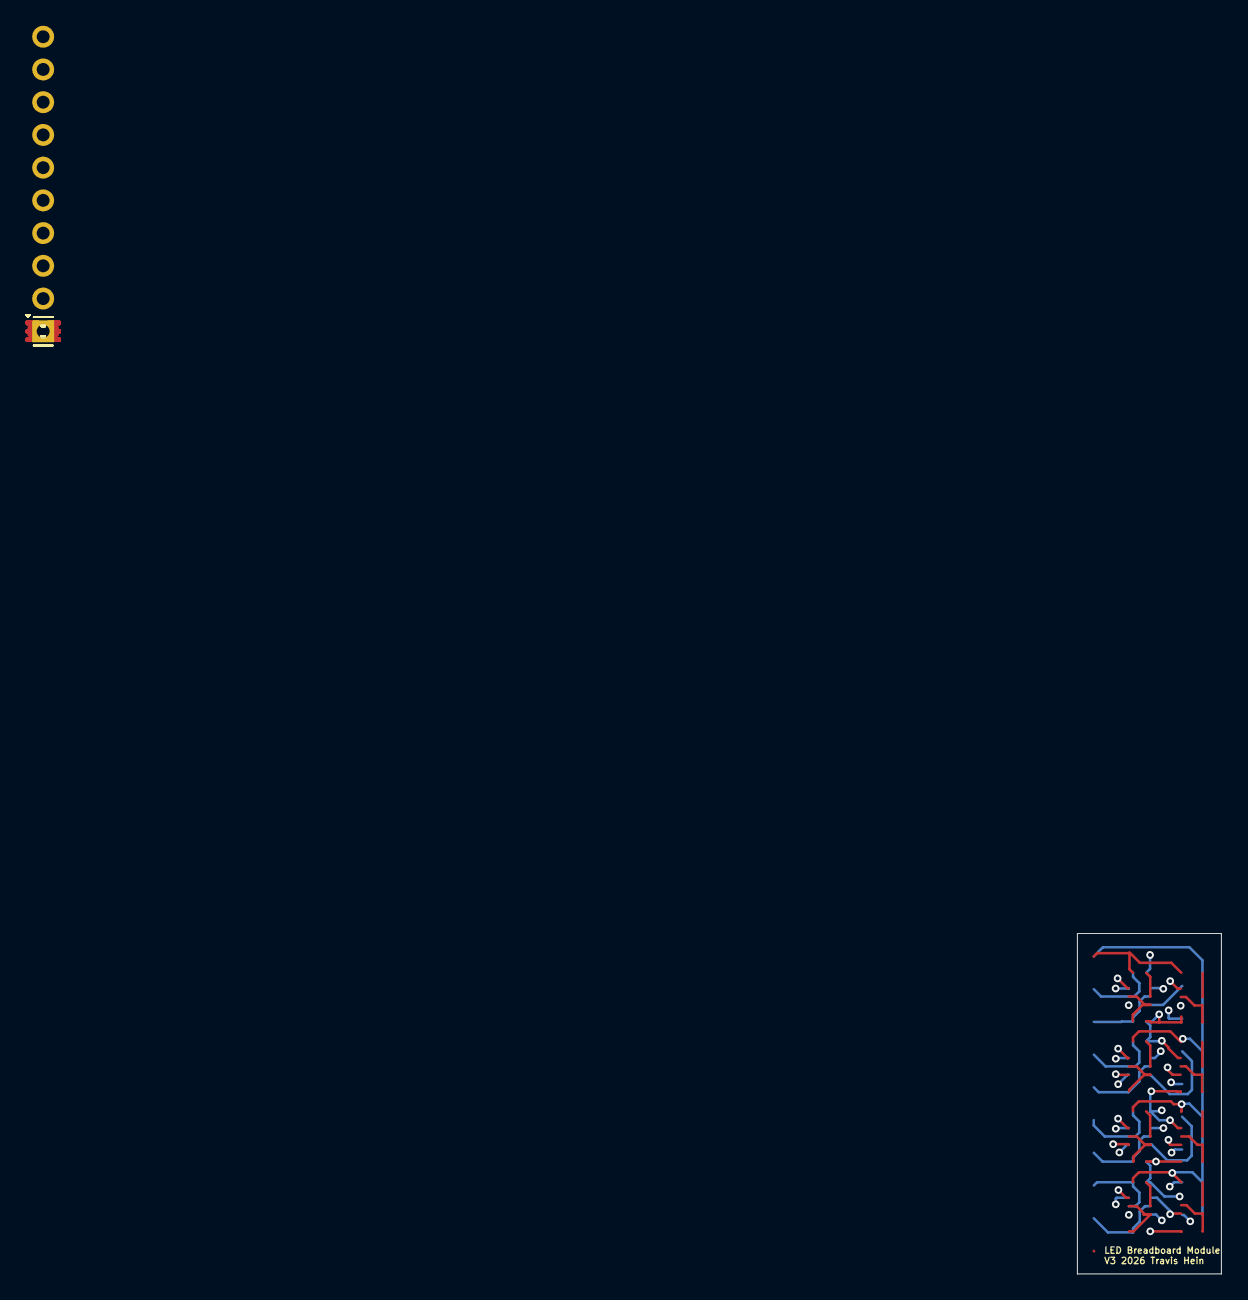
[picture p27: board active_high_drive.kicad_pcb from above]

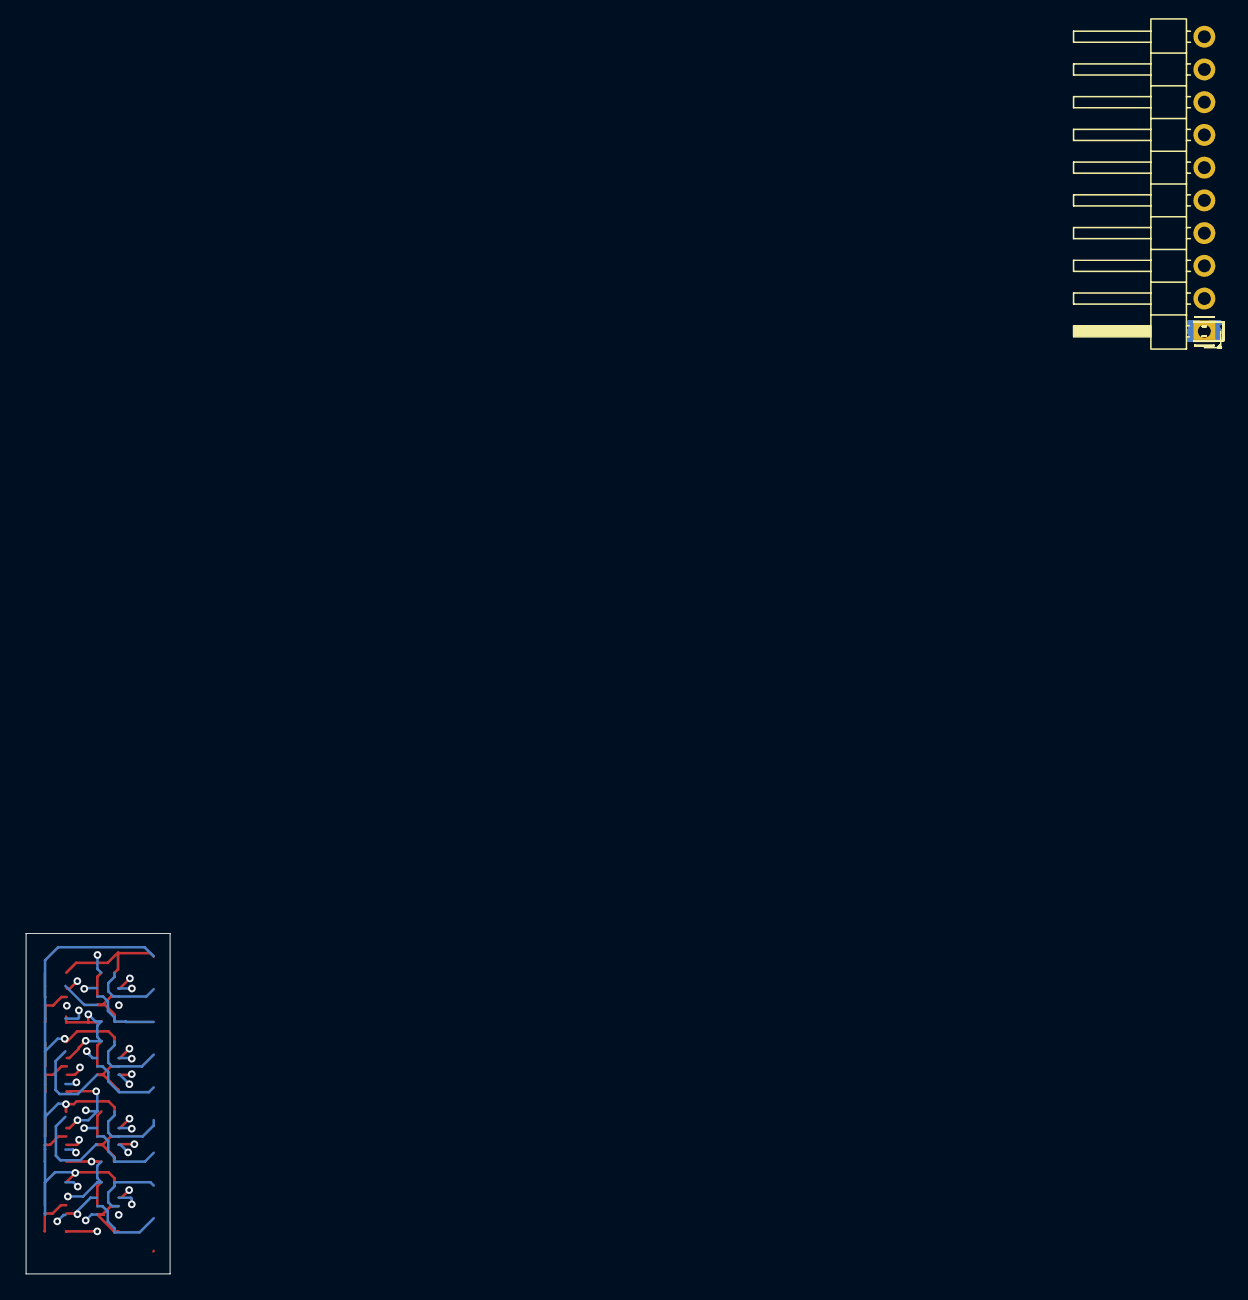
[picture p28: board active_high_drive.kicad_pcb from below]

Board: 4 copper layers, 11.2 x 26.4 mm, 46 parts (21 on the bottom side), 42 nets.

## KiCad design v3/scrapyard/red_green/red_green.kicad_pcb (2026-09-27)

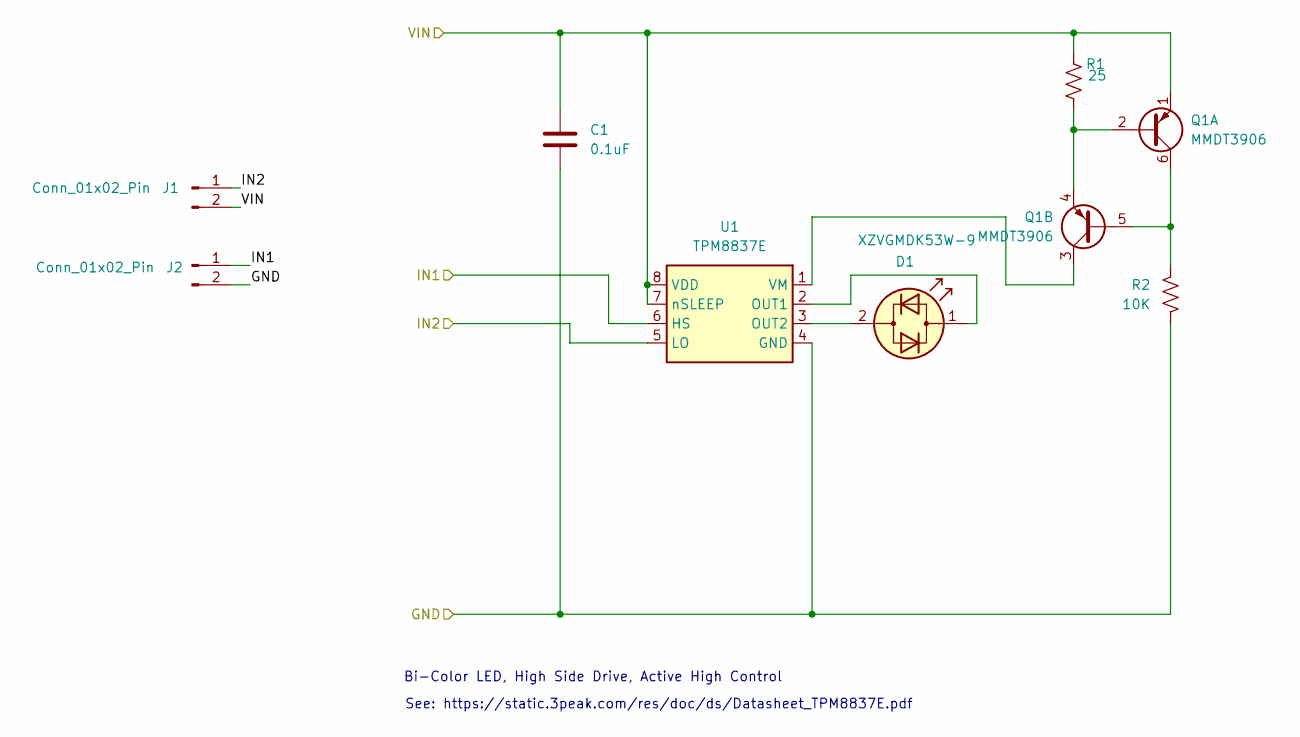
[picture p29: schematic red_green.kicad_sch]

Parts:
C1: 0.1uF; C_0603_1608Metric
D1: XZVGMDK53W-9; LED_0603_1608Metric
J1, J2: Conn_01x02_Pin; PinHeader_1x02_P2.54mm_Vertical
Q1: MMDT3906; SOT-363_SC-70-6
R1: 25; R_0603_1608Metric
R2: 10K; R_0603_1608Metric
U1: TPM8837E; DFN-8-1EP_2x2mm_P0.5mm_EP0.6x1.2mm

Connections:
/GND: C1.2, J2.2, R2.2, U1.4 (GND)
/IN1: J2.1, U1.6 (HS)
/IN2: J1.1, U1.5 (LO)
/VIN: C1.1, J1.2, Q1.1 (E1), R1.1, U1.7 (nSLEEP), U1.8 (VDD)
unnamed: D1.2 (AK), U1.3 (OUT2)
unnamed: D1.1 (KA), U1.2 (OUT1)
unnamed: Q1.2 (B1), Q1.4 (E2), R1.2
unnamed: Q1.5 (B2), Q1.6 (C1), R2.1
unnamed: Q1.3 (C2), U1.1 (VM)

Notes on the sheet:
See: https://static.3peak.com/res/doc/ds/Datasheet_TPM8837E.pdf
Bi-Color LED, High Side Drive, Active High Control

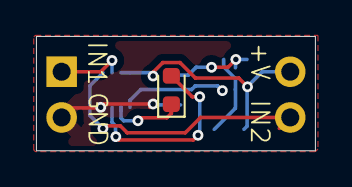
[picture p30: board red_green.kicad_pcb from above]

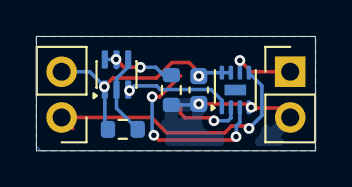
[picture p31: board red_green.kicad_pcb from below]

Board: 2 copper layers, 15.5 x 6.4 mm, 8 parts (7 on the bottom side), 9 nets.

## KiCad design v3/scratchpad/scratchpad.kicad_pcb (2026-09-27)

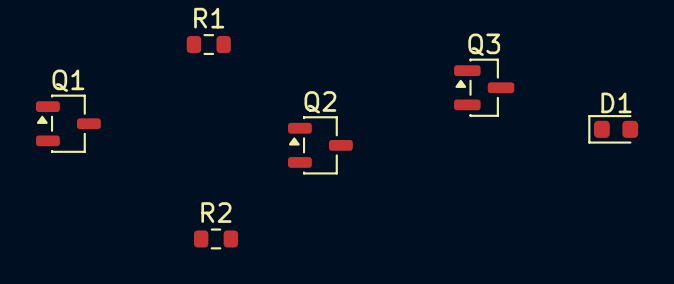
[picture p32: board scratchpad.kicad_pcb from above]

Board: 2 copper layers, 6 parts (0 on the bottom side), 6 nets, no tracks yet.

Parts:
D1: LIST-C191K; LED_0603_1608Metric
Q1, Q2: MMTB3904; SOT-23-3
Q3: BSS138; SOT-23
R1: 10K; R_0603_1608Metric
R2: 68; R_0603_1608Metric

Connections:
/V+: D1.2 (A), R1.2
/V-: Q1.2 (E), R2.2
unnamed: D1.1 (K), Q2.3 (C)
unnamed: Q1.1 (B), Q3.2 (S), R2.1
unnamed: Q1.3 (C), Q2.1 (B), R1.1
unnamed: Q2.2 (E), Q3.3 (D)

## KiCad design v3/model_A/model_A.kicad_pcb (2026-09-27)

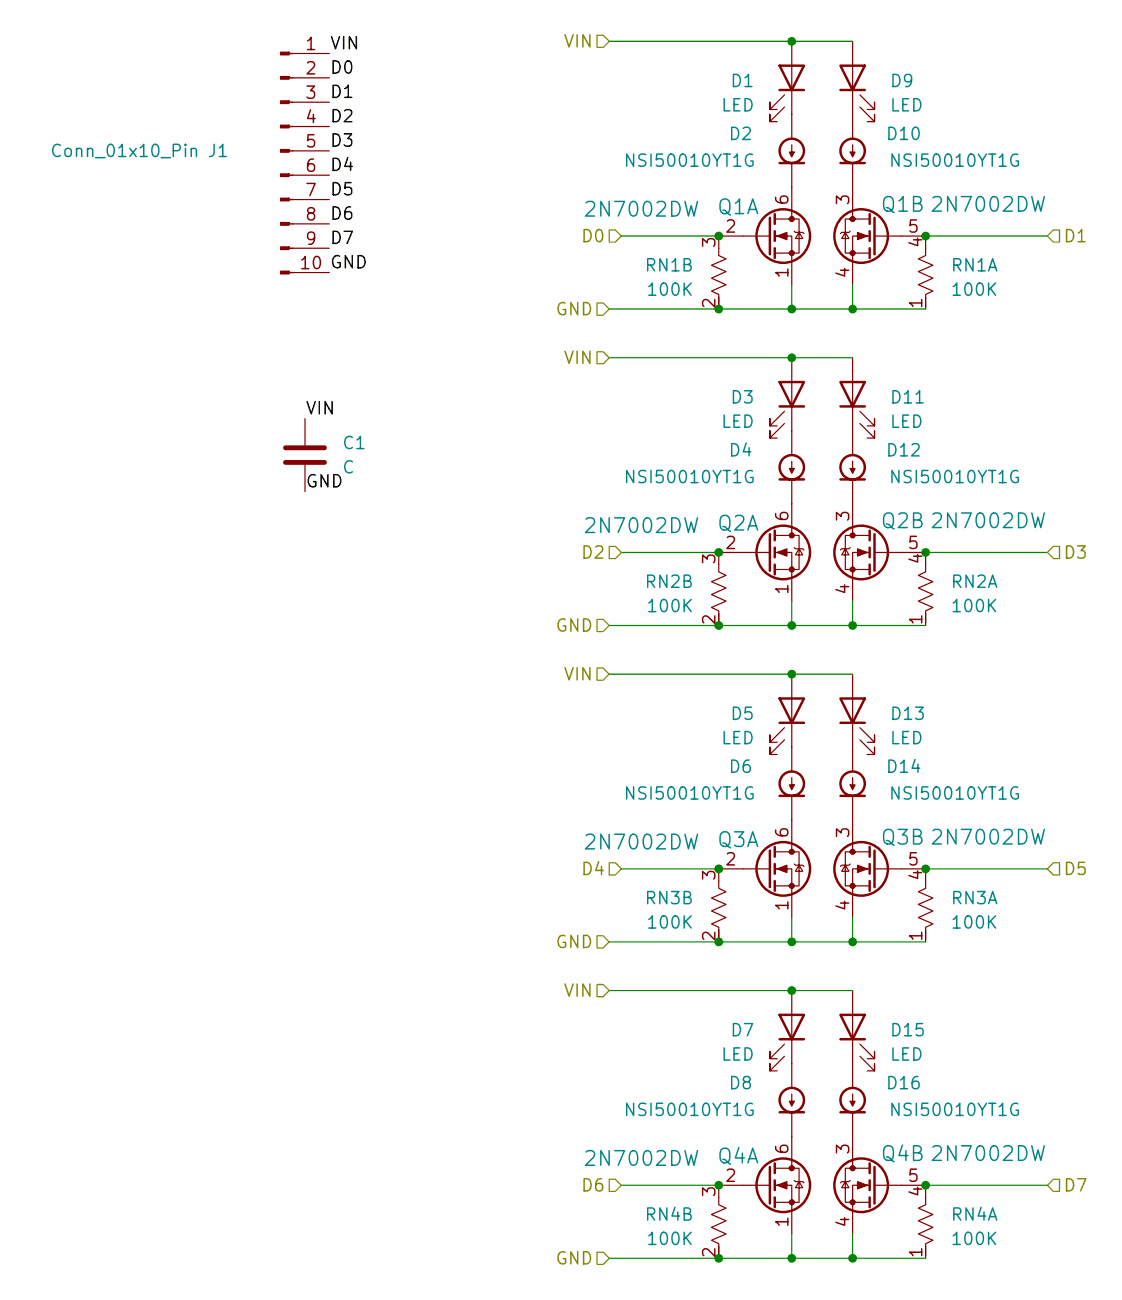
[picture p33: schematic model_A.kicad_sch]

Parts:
C1: C; C_0603_1608Metric
D1, D3, D5, D7, D9, D11, D13, D15: LED; LED_0603_1608Metric
D2, D4, D6, D8, D10, D12, D14, D16: NSI50010YT1G; D_SOD-123
J1: Conn_01x10_Pin; PinHeader_1x10_P2.54mm_Horizontal
Q1, Q2, Q3, Q4: 2N7002DW; SOT-363_SC-70-6
RN1, RN2, RN3, RN4: 100K; R_Array_Convex_2x0402

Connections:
/D0: J1.2, Q1.2 (G), RN1.3 (R1)
/D1: J1.3, Q1.5 (G), RN1.4 (R1)
/D2: J1.4, Q2.2 (G), RN2.3 (R1)
/D3: J1.5, Q2.5 (G), RN2.4 (R1)
/D4: J1.6, Q3.2 (G), RN3.3 (R1)
/D5: J1.7, Q3.5 (G), RN3.4 (R1)
/D6: J1.8, Q4.2 (G), RN4.3 (R1)
/D7: J1.9, Q4.5 (G), RN4.4 (R1)
/GND: C1.2, J1.10, Q1.1 (S), Q1.4 (S), Q2.1 (S), Q2.4 (S), Q3.1 (S), Q3.4 (S), Q4.1 (S), Q4.4 (S), RN1.1 (R1.2), RN1.2 (R2.2), RN2.1 (R1.2), RN2.2 (R2.2), RN3.1 (R1.2), RN3.2 (R2.2), RN4.1 (R1.2), RN4.2 (R2.2)
/VIN: C1.1, D1.2 (A), D3.2 (A), D5.2 (A), D7.2 (A), D9.2 (A), D11.2 (A), D13.2 (A), D15.2 (A), J1.1
unnamed: D1.1 (K), D2.2 (A)
unnamed: D2.1 (K), Q1.6 (D)
unnamed: D3.1 (K), D4.2 (A)
unnamed: D4.1 (K), Q2.6 (D)
unnamed: D5.1 (K), D6.2 (A)
unnamed: D6.1 (K), Q3.6 (D)
unnamed: D7.1 (K), D8.2 (A)
unnamed: D8.1 (K), Q4.6 (D)
unnamed: D9.1 (K), D10.2 (A)
unnamed: D10.1 (K), Q1.3 (D)
unnamed: D11.1 (K), D12.2 (A)
unnamed: D12.1 (K), Q2.3 (D)
unnamed: D13.1 (K), D14.2 (A)
unnamed: D14.1 (K), Q3.3 (D)
unnamed: D15.1 (K), D16.2 (A)
unnamed: D16.1 (K), Q4.3 (D)

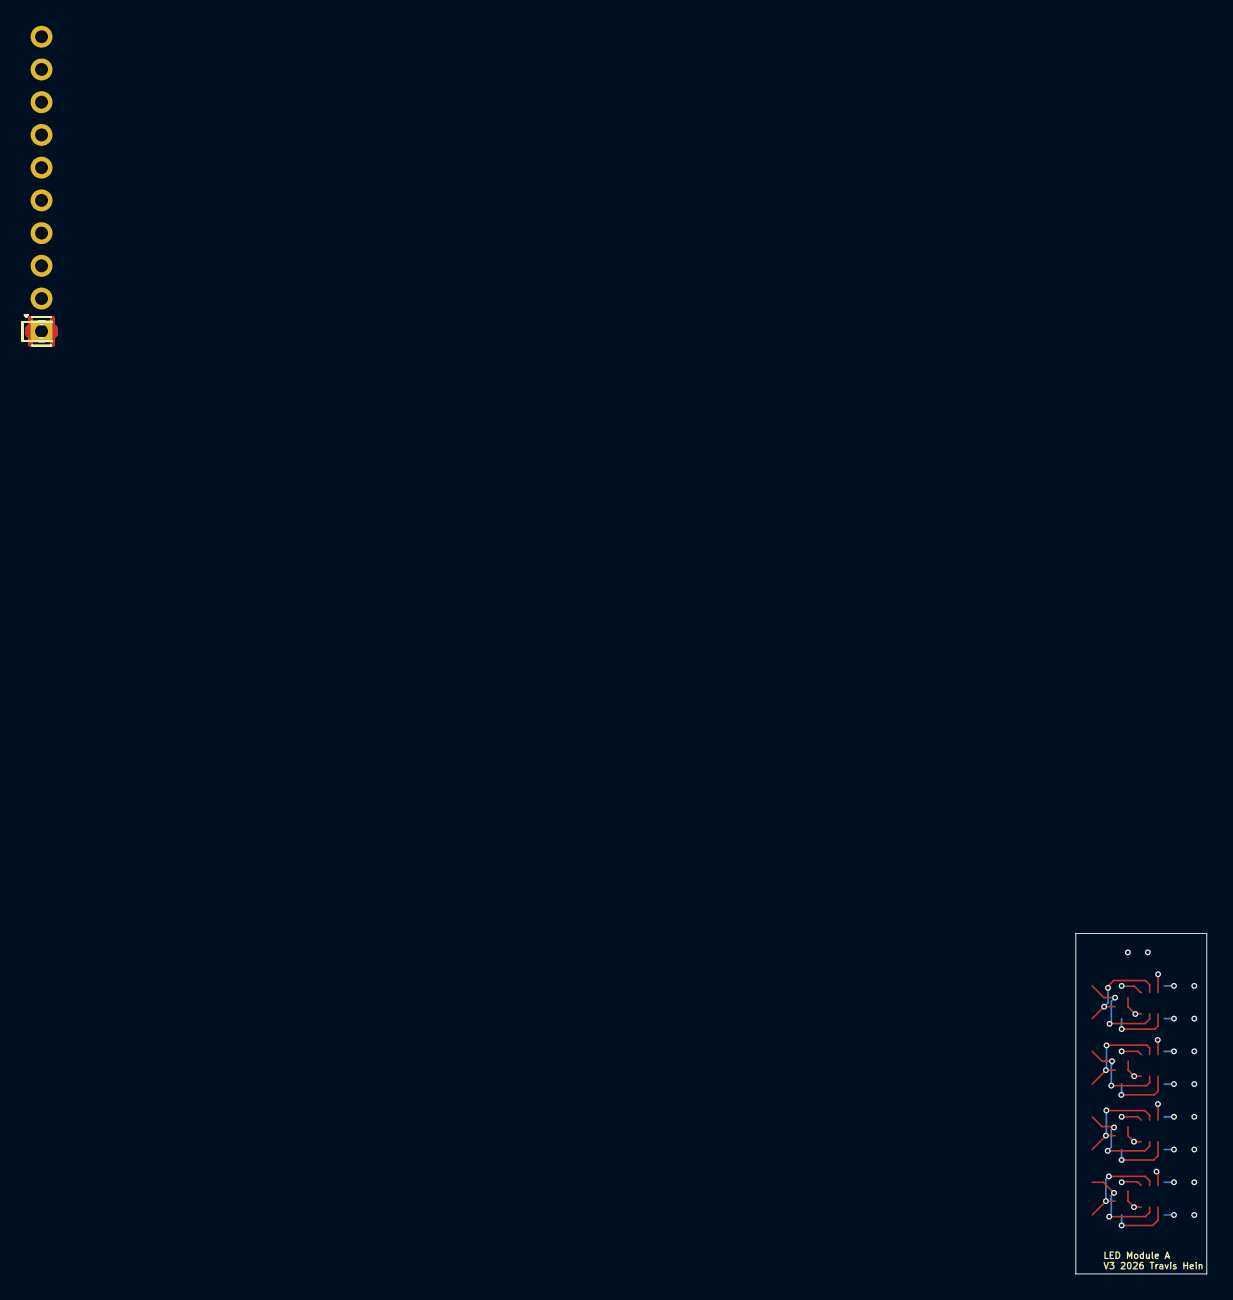
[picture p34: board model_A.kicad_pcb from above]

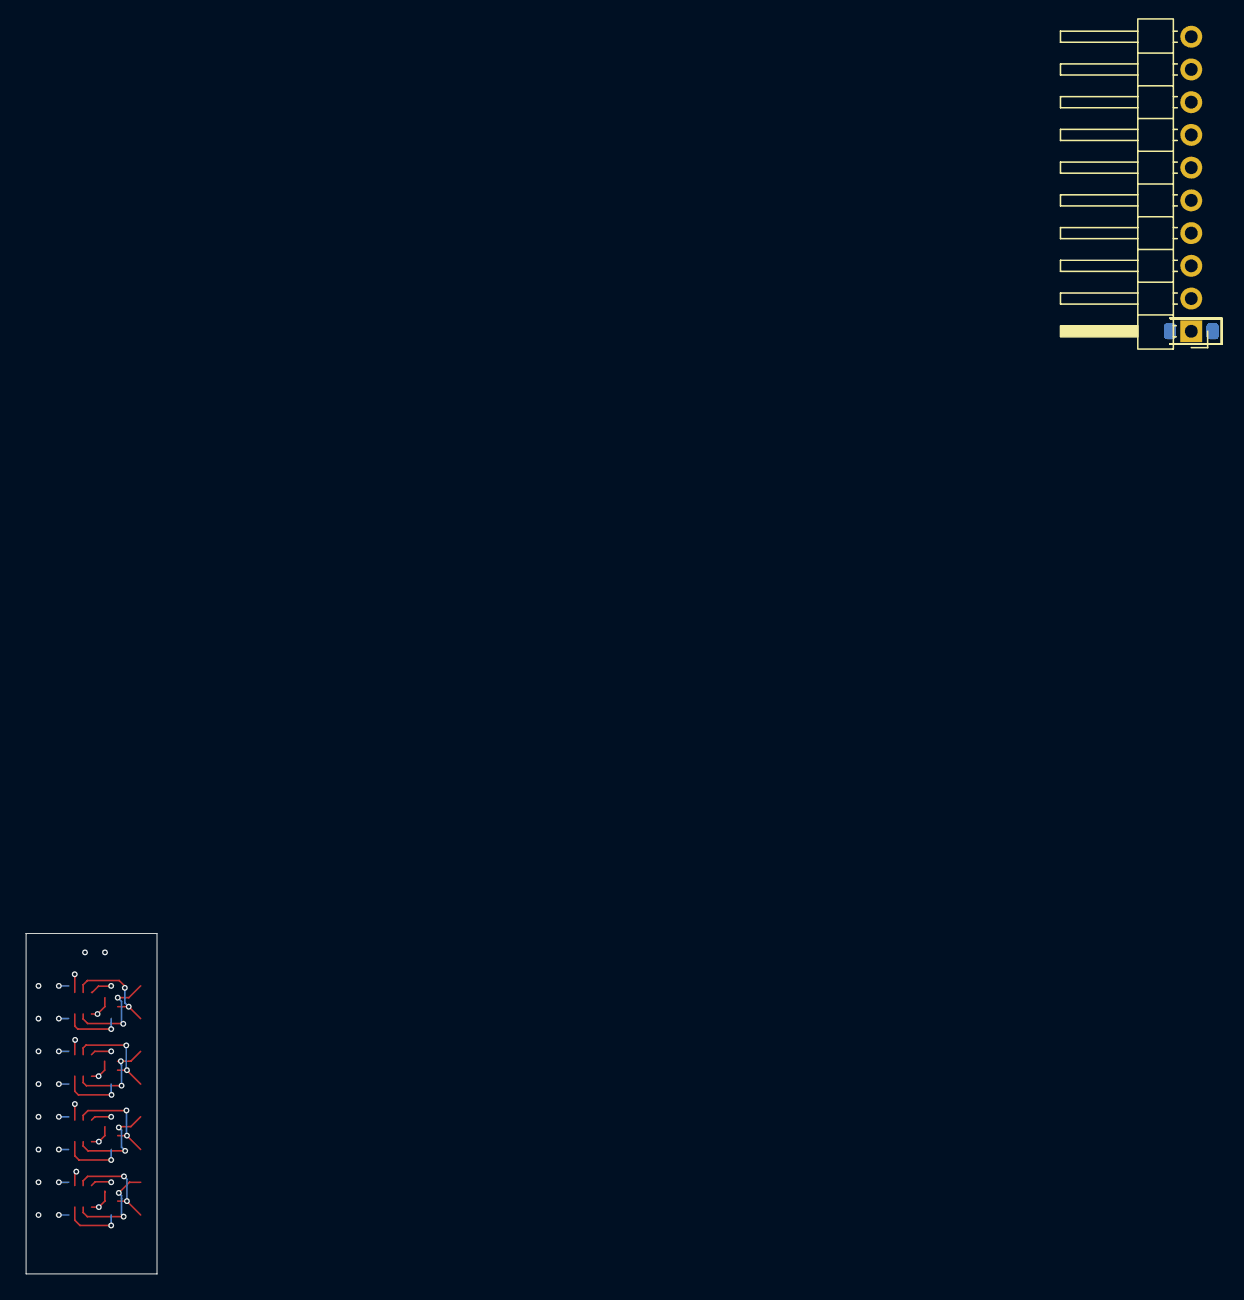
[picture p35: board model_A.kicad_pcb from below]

Board: 4 copper layers, 10.2 x 26.4 mm, 26 parts (9 on the bottom side), 26 nets.

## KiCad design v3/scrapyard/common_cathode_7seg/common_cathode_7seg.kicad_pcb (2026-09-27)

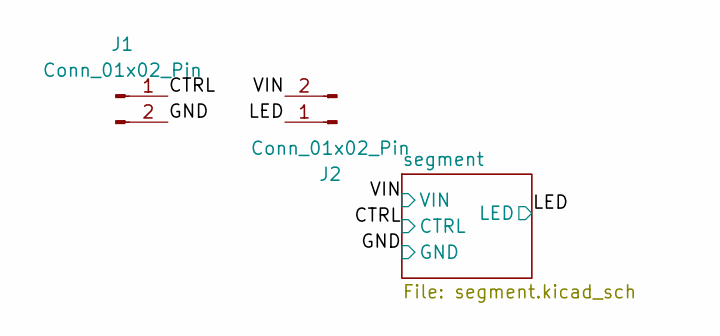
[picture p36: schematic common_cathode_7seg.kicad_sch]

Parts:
J1, J2: Conn_01x02_Pin; Conn_Mill-Max_0508_1x02_P2.54mm

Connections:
/CTRL: J1.1; also elsewhere on the board
/GND: J1.2; also elsewhere on the board
/LED: J2.1; also elsewhere on the board
/VIN: J2.2; also elsewhere on the board


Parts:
Q1: NTJD4105C; SOT-363_SC-70-6
Q4: MMDT3906; SOT-363_SC-70-6
R2: 100K; R_0603_1608Metric
R5: 10K; R_0603_1608Metric
R6: 33; R_0603_1608Metric

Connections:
/CTRL: Q1.2 (G), R2.1; also elsewhere on the board
/GND: Q1.1 (S), R2.2; also elsewhere on the board
/LED: Q4.3 (C2); also elsewhere on the board
/VIN: Q4.1 (E1), R6.1; also elsewhere on the board
unnamed: Q1.6 (D), R5.2
unnamed: Q4.2 (B1), Q4.4 (E2), R6.2
unnamed: Q4.5 (B2), Q4.6 (C1), R5.1

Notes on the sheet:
Single LED, High Side Drive, Active High Control



Board: 2 copper layers, 7.5 x 6.4 mm, 7 parts (2 on the bottom side), 7 nets.

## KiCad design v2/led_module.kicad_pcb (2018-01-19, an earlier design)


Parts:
C1: 0.1µF; C_0603
D1, D2, D3, D4, D5, D6, D7, D8: LTST-C190EKT; LED_0603
P1: CONN_01X10; Header_pins_2.54mm_1x10
Q1, Q2, Q3, Q4, Q5, Q6, Q7, Q8: MMBT3904L; SOT-23
R1, R2, R3, R4, R5, R6, R7, R8: 4.7K; R_0603
R9, R10, R11, R12, R13, R14, R15, R16: 10K; R_0603
R17, R18, R19, R20, R21, R22, R23, R24: 100; R_0603

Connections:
/GND: C1.1, P1.1, Q1.2 (E), Q2.2 (E), Q3.2 (E), Q4.2 (E), Q5.2 (E), Q6.2 (E), Q7.2 (E), Q8.2 (E), R9.2, R10.2, R11.2, R12.2, R13.2, R14.2, R15.2, R16.2
/VCC: C1.2, D1.2 (A), D2.2 (A), D3.2 (A), D4.2 (A), D5.2 (A), D6.2 (A), D7.2 (A), D8.2 (A), P1.10
/led1: P1.2, R1.2
/led2: P1.3, R2.2
/led3: P1.4, R3.2
/led4: P1.5, R4.2
/led5: P1.6, R5.2
/led6: P1.7, R6.2
/led7: P1.8, R7.2
/led8: P1.9, R8.2
unnamed: D1.1 (K), R17.2
unnamed: D2.1 (K), R18.2
unnamed: D3.1 (K), R19.2
unnamed: D4.1 (K), R20.2
unnamed: D5.1 (K), R21.2
unnamed: D6.1 (K), R22.2
unnamed: D7.1 (K), R23.2
unnamed: D8.1 (K), R24.2
unnamed: Q1.1 (B), R1.1, R9.1
unnamed: Q1.3 (C), R17.1
unnamed: Q2.1 (B), R2.1, R10.1
unnamed: Q2.3 (C), R18.1
unnamed: Q3.1 (B), R3.1, R11.1
unnamed: Q3.3 (C), R19.1
unnamed: Q4.1 (B), R4.1, R12.1
unnamed: Q4.3 (C), R20.1
unnamed: Q5.1 (B), R5.1, R13.1
unnamed: Q5.3 (C), R21.1
unnamed: Q6.1 (B), R6.1, R14.1
unnamed: Q6.3 (C), R22.1
unnamed: Q7.1 (B), R7.1, R15.1
unnamed: Q7.3 (C), R23.1
unnamed: Q8.1 (B), R8.1, R16.1
unnamed: Q8.3 (C), R24.1


Board: 2 copper layers, 15.9 x 29.2 mm, 42 parts (0 on the bottom side), 34 nets.

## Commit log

2018-01-19 import files previously in the kicad proect folder
    [led_module.kicad_pcb, led_module.sch]
2020-09-28 check out and rescue symbols
    [led_module-2020-09-27-21-47-08.sch]
2021-04-26 start a v3 design
    [mosfet_input.sch, single_led.sch, v3.kicad_pcb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]
2026-06-30 local mods
    [led_module-2020-09-27-21-47-08.sch, led_module.kicad_pcb, led_module.sch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]
2026-07-02 fighting with freecad and updating documentation
    [ledbit.kicad_pcb, ledbit.kicad_sch, mosfet_input.sch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]
2026-08-16 feat: design a module for red/green led
    a 4 pin narrow breadboard module.
    [ledbit.kicad_pcb, ledbit.kicad_sch, red_green.kicad_pcb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]
2026-08-17 feat: boards for v3.1 red and red-green modules
    [active_high_drive.kicad_pcb, active_high_drive.kicad_sch, paid.kicad_sch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]
2026-09-27 feat: iterating on v3 design
    [active_high_drive.kicad_pcb, active_high_drive.kicad_sch, active_low_drive.kicad_pcb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]
2026-09-27 update documentation
    [paid.kicad_sch]
